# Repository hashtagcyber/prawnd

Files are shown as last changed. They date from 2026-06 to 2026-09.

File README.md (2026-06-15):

# Prawnd

An ESP32-based, Plaud-style voice recorder. Press a button to start/stop recording;
the device captures 16 kHz stereo audio to an SD card and POSTs each finished WAV
to a webserver you configure on-device.

- **Hardware** — Seeed XIAO ESP32C6, 2× INMP441 I²S mics (stereo), SPI microSD adapter, push-button. Wiring diagrams live in [`hardware/wiring.md`](hardware/wiring.md).
- **Firmware** — Arduino-ESP32 via PlatformIO. Source in [`firmware/`](firmware/).
- **Webservice** — Node.js + Fastify, SQLite-indexed, Dockerized. Source in [`server/`](server/).

> [!CAUTION]
> ## 🔓 HTTPS uploads use `setInsecure()` — TLS certificate validation is OFF
>
> When the configured Upload URL is `https://…`, the firmware uploads with
> `WiFiClientSecure::setInsecure()` (`firmware/src/uploader.cpp`), which **does
> the TLS handshake but does NOT validate the server's certificate**. The
> connection is encrypted, but there is **no protection against a
> man-in-the-middle**: anyone who can intercept the device's traffic can present
> a forged certificate, decrypt the upload, and **steal the API key** (which the
> device sends as `Authorization: Bearer …`).
>
> This is a **beta convenience only.** Before any non-hobby/production use, pin a
> CA bundle (e.g. ISRG Root X1) via `setCACert()` and remove `setInsecure()`, and
> treat each device's API key as compromised if its network is ever untrusted.
> Rotate keys in the web UI if in doubt.

## Quick start

```bash
# 1. Bring the server up locally
cd server
cp .env.example .env            # then edit PRAWND_API_KEY
docker compose up -d --build
curl -s http://localhost:8080/healthz   # {"ok":true}

# 2. Build the firmware
cd ../firmware
pio run                                  # first run downloads toolchains (slow)

# 3. Flash it (with the XIAO plugged in via USB-C)
pio run -t upload
pio device monitor                       # 115200 baud
```

On first boot the device has no WiFi configured, so it brings up an AP named
**`Prawnd-XXXX`** (password `prawnd1234`). Connect, browse to `http://192.168.4.1`,
fill in WiFi creds + upload URL + API key, hit save. The device reboots into STA
mode and is ready to record.

## Server

### Prereqs
- Docker / Docker Compose (Rancher Desktop, OrbStack, or Docker Desktop all fine)

### Build & run
```bash
cd server
cp .env.example .env       # set PRAWND_API_KEY
docker compose up -d --build
docker compose logs -f prawnd
```

The container exposes port `8080`, persists data under `./data/` on the host
(SQLite at `data/prawnd.sqlite`, WAVs under `data/audio/<device_id>/<yyyy>/<mm>/`).

### Browser UI

Visit `http://localhost:8080/` for a built-in single-page UI: enter your API key
once (cached in `localStorage`), filter by device id, and play back any recording
inline. Audio elements stream from `/recordings/:id/file?api_key=...` directly.
**Caveat**: the API key ends up in `<audio src>` attributes, so treat the URL as
secret on the LAN — don't share screenshots of the DOM.

### Endpoints

| Method | Path | Auth | Purpose |
|---|---|---|---|
| `GET`  | `/` | no | Built-in HTML UI. |
| `POST` | `/upload` | yes | Upload a WAV body. Headers: `Authorization: Bearer <key>` (or `X-API-Key: <key>`), `Content-Type: audio/wav`, `X-Device-Id: <id>`, `X-Client-Timestamp: <ms>` (optional). |
| `GET`  | `/recordings?limit=&cursor=&device_id=` | yes | Cursor-paginated list, newest first. |
| `GET`  | `/recordings/:id` | yes | JSON metadata. |
| `GET`  | `/recordings/:id/file` | yes | Raw `audio/wav` download. Auth accepts `?api_key=` query for `<audio>` playback. |
| `GET`  | `/healthz` | no | Liveness. |

API key auth accepts any of: `Authorization: Bearer <key>` header, `X-API-Key: <key>` header, or `?api_key=<key>` query param.

### Manual upload (smoke test without firmware)
```bash
curl -fsS -X POST \
  -H "Authorization: Bearer $PRAWND_API_KEY" \
  -H "Content-Type: audio/wav" \
  -H "X-Device-Id: bench" \
  --data-binary @some.wav \
  http://localhost:8080/upload
curl -fsS -H "Authorization: Bearer $PRAWND_API_KEY" http://localhost:8080/recordings | jq
```

### Stop / clean
```bash
docker compose down            # stop
rm -rf data && mkdir data      # wipe all recordings + db
```

## Firmware

### Prereqs
- [PlatformIO Core](https://platformio.org/install/cli) (`brew install platformio` on macOS)
- A USB-C cable that carries data
- A microSD card formatted **FAT32**

### Build
```bash
cd firmware
pio run
```
First run pulls the `espressif32` platform, the Arduino-ESP32 framework, the
toolchain, and the listed libs — expect several minutes on a fresh machine.
Subsequent builds take seconds. The flashable binary lands at
`.pio/build/xiao_esp32c6/firmware.bin`.

### Flash
Plug the XIAO in via USB-C. The C6 enters bootloader automatically on most
ports; if not, hold the **BOOT** button, tap **RESET**, then release BOOT.

The compiled artifact is `.pio/build/xiao_esp32c6/firmware.bin` (~1.1 MB).
```bash
pio run -t upload                # build + flash
pio run -t upload -t monitor     # flash + open serial monitor
```
Set the port explicitly if PlatformIO can't auto-detect:
```bash
pio run -t upload --upload-port /dev/cu.usbmodem<TAB>
```

### Serial monitor
```bash
pio device monitor               # 115200 baud (configured in platformio.ini)
```

### Optional: battery-monitoring addon

A second PlatformIO env, **`xiao_esp32c6_batt`**, compiles in an optional
MAX17048 LiPo fuel-gauge driver. The base `xiao_esp32c6` build is unchanged — the
addon is purely a compile-time flag (`-DENABLE_BATTERY`), so the standard
USB-powered firmware carries no battery code.

```bash
pio run -e xiao_esp32c6_batt              # build the battery variant
pio run -e xiao_esp32c6_batt -t upload    # build + flash it
```

Wire a MAX17048 breakout to the XIAO's I²C pins (`D4`=SDA, `D5`=SCL) and the BAT
pads — see [`hardware/wiring.md`](hardware/wiring.md#battery-fuel-gauge--max17048-optional-addon).
When a gauge is detected, `GET /status` gains `batt_pct` and `batt_mv` fields and
the config page shows the charge level; with no gauge fitted it reports
`battery: n/a` and behaves identically to the base firmware. The artifact lands
at `.pio/build/xiao_esp32c6_batt/firmware.bin`.

### First-time WiFi + upload setup
1. After flash, the device has no NVS config → it boots into AP mode.
2. From a phone or laptop, join the WiFi network **`Prawnd-XXXX`** (password `prawnd1234`, where `XXXX` is the last 4 hex of the MAC).
3. Open `http://192.168.4.1`.
4. Enter:
   - WiFi SSID + password (your home/office WiFi)
   - Upload URL — either:
     - **Local server:** `http://<your-mac-IP>:8080/upload` (plain HTTP), or
     - **Hosted beta:** `https://prawnd.dev.cobl.io/upload` (HTTPS — see the
       certificate-validation caution at the top of this README).
   - API key:
     - Local server: must match the server's `PRAWND_API_KEY`.
     - Hosted beta: log in at `https://prawnd.dev.cobl.io` with cobl.io and
       generate an **upload key** under *API keys*.
   - Device id (optional; auto-derived from MAC)
5. Hit **Save and reboot**. The device reconnects in STA mode.

To find the device's IP after reboot, watch the serial monitor or check your
router's DHCP list. `GET http://<device-ip>/status` returns its current state.

### Troubleshooting the first build

The `firmware/platformio.ini` deliberately uses the **pioarduino** platform fork
(`https://github.com/pioarduino/platform-espressif32/releases/...`) because the
official `platform-espressif32` still bundles Arduino-ESP32 v2.x, which has no
ESP32-C6 support. Two snags you may hit on a fresh machine:

- **`Could not find a version that satisfies the requirement cryptography` from pip** — your global pip is pointing at a local mirror that isn't serving. Override for the one command: `PIP_INDEX_URL=https://pypi.org/simple/ pio run`.
- **`FileNotFoundError: 'package-postinstall.py'` from the pioarduino esptool zip** — the v4.8.6 release omits the post-install script that PlatformIO tries to run. Stub it once: `touch ~/.platformio/packages/tool-esptoolpy/package-postinstall.py`, then re-run `pio run`.

### Recording flow
- **Short-press button** — start recording (LED on board lights, serial logs path)
- **Short-press again** — stop, patch WAV header, queue for upload, POST to server
- **Long-press ≥ 5 s** — factory reset (wipes NVS, reboots into AP mode)

Pending uploads (WiFi down, server unreachable) land in `/pending/` on the SD
card and retry once a minute while the device is idle and connected. Successfully
uploaded files move to `/uploaded/`.

## End-to-end verification

1. `cd server && docker compose up -d` — confirm `/healthz` returns 200.
2. `cd ../firmware && pio run -t upload && pio device monitor` — flash and watch boot logs.
3. Join the AP, configure with the upload URL pointing at your machine's LAN IP (NOT `localhost` — that's the device's own loopback).
4. Press the button, speak for a few seconds, press again.
5. Watch the serial log for `Upload .../ -> 200`.
6. `curl -fsS -H "Authorization: Bearer $PRAWND_API_KEY" http://localhost:8080/recordings | jq` — your recording shows up at the top.
7. Pull the file: `curl -fsS -H "Authorization: Bearer $PRAWND_API_KEY" http://localhost:8080/recordings/<id>/file -o out.wav` and play in VLC/Audacity — both L and R channels should be populated.

## Project layout

```
prawnd/
├── README.md
├── hardware.md                # high-level spec
├── hardware/
│   └── wiring.md              # per-device wiring diagrams + pin map
├── firmware/
│   ├── platformio.ini
│   ├── include/pins.h
│   └── src/                   # main, audio, wav, sd, wifi, portal, uploader, button, config,
│                              #   battery (optional MAX17048 addon, -DENABLE_BATTERY)
└── server/
    ├── Dockerfile
    ├── docker-compose.yml
    ├── package.json
    ├── .env.example
    └── src/                   # server.js, db.js, auth.js, wav.js,
                               #   routes/ (upload, recordings, health, ui)
```

## Hardware Links
I purchased the following parts on Amazon:
- https://a.co/d/0gR9T4nS
- https://a.co/d/04cU7Vte
- https://a.co/d/02JYXZO7
- https://a.co/d/06rkL2Dp

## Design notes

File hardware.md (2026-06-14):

# Prawnd
ESP32 Clone of Plaud

The device has a configuration page where you can enter a URL and API key. When a recording completes, it's automatically uploaded to a webserver
The same page is how you configure the wifi access.

A start/stop button is used to start/stop recording

## Hardware
- 1x Seeed Studio XIAO ESP32C6
- 2x INMP441
- 1x WWZMDiB 6 Pcs Micro SD TF Card Adapter Mini Reader Module 3.3V 6 Pin SPI Interface
- 1x button
- *(optional)* 1x MAX17048 LiPo fuel-gauge breakout + single-cell LiPo — battery-monitoring addon, see `hardware/wiring.md`

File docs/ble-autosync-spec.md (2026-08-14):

# Prawnd BLE Auto-Sync Rearchitecture — Implementation Spec

Status: implementation-ready. Version 1.0. Audience: two implementation agents
(Firmware; iOS + Server). Section **B (Shared BLE Contract)** is the binding
coordination boundary — both sides implement only against it and must not need
to talk to each other. Sections C/D/E are per-agent. F/G/H apply to both.

> Hardware note (verified against `firmware/platformio.ini`): the firmware
> targets a **Seeed XIAO ESP32-C6** (not an ESP32-S3 as the brief states). The
> spec is written for the C6; everything here is SoC-agnostic except memory
> budgets, which assume the C6's single RISC-V core + ~512 KB SRAM. This does
> not change the BLE contract.

---

## A. Overview & Goals

### Target architecture

Today the device drains its on-SD `/pending/*.wav` queue via **two** uplinks: a
firmware WiFi HTTPS uploader (`uploader.cpp`, states `ApPortal`/`Uploading`) and
an iOS app over a custom BLE GATT contract. The rearchitecture **removes WiFi
entirely from the firmware** and makes **the phone-over-BLE path the sole
uplink**. The firmware no longer knows the server URL or API key — those live
only in the iOS app. The device only: records audio, queues WAVs to SD, serves
them over BLE, and advertises *whether it has pending recordings* so iOS can
discover-and-wake the app in the background.

Three roles:

- **Device (ESP32-C6, NimBLE peripheral):** records to `/pending`, advertises a
  "pending present" bit, serves a reliable chunked file-transfer GATT service,
  moves files `/pending → /uploaded` on ACK, clears the pending bit when the
  queue empties.
- **iOS app (Core Bluetooth central, background-capable):** holds the server
  credentials, auto-connects to the bonded device when it sees the pending bit
  (even when backgrounded/relaunched via Core Bluetooth **state restoration**),
  drains the queue reliably, POSTs each WAV to the server, ACKs the device.
- **Server (Node/Fastify):** unchanged contract plus **content-hash
  idempotency** so a retried background upload never double-stores.

The key constraint driving the whole design: **iOS background BLE is slow and
its wake windows are short.** Background scanning is coalesced/duty-cycled by
the OS, cannot use `CBCentralManagerScanOptionAllowDuplicatesKey`, and *requires
explicit service UUIDs in the scan filter* (a service UUID present only in the
scan-response is invisible to background scans). A background wake from a BLE
discovery grants only a few seconds of runtime — not enough to pull a multi-MB
WAV and HTTP-POST it inline. We therefore design so that:

1. The device advertises the **128-bit service UUID in the primary advertising
   packet** (not scan-response) at all times, so iOS background scan can match.
2. The **HTTP upload is handed to a background `URLSession`** (out-of-process,
   OS-managed, survives app suspension/termination), so the wake window only has
   to cover BLE pull + enqueue, not the network transfer.
3. The BLE transfer itself is **reliable and resumable** (length-prefixed,
   CRC'd, windowed-ACK chunks) so a wake window that ends mid-file can resume on
   the next wake instead of restarting.

This is the best achievable on iOS. See **H** for the honest limits (notably:
true "app fully closed" wake works only via state restoration after at least one
launch, and large files may take several wake windows).

### End-to-end happy path (ASCII sequence)

```
 USER        DEVICE (ESP32-C6)                 iOS APP (bg)              SERVER
  |   press        |                                |                       |
  |--------------->| record -> /pending/<ts>.wav    |                       |
  |   press        | patch WAV header               |                       |
  |--------------->| stopRecording()                |                       |
  |                | set PENDING bit in adv mfg-data|                       |
  |                | advertise(svcUUID in primary,  |                       |
  |                |           pending=1)            |                       |
  |                |        ~~~ adv ~~~~~~~~~~~~~~~~> | OS bg scan match      |
  |                |                                 | (relaunch app if     |
  |                |                                 |  killed, via state    |
  |                |                                 |  restoration)         |
  |                |                                 | connect(known periph) |
  |                | onConnect (encrypted, bonded)  <-| (no timeout in bg)   |
  |                | link encrypts (resolve RPA)    <-> bond resolves        |
  |                |                                 | discover svc/chars    |
  |                |                                 | subscribe DATA/STAT   |
  |                |<-- CTRL: LIST ------------------|                       |
  |                |--- STAT: F <name> <size> <crc> >|                       |
  |                |--- STAT: FEND <count> -------- >|                       |
  |                |<-- CTRL: GET <name> <off=0> --- |                       |
  |                |--- STAT: GS <name> <size> <crc> >|                      |
  |                |--- DATA: [seq|len|payload] ---->| (window of N)         |
  |                |<-- CTRL: ACKW <next_seq> ------ | (windowed ACK)        |
  |                |--- DATA: ... -----------------> | ... until EOF         |
  |                |--- STAT: GE <name> <crc_ok> -- >| verify CRC            |
  |                |                                 | enqueue bg URLSession |
  |                |                                 |---- POST /upload ----->|
  |                |                                 |   (X-Content-Sha256)  |
  |                |                                 |<--- 200 {id} / 409 ---|
  |                |<-- CTRL: ACK <name> ----------- | (after 2xx OR 409 dup)|
  |                | mv /pending/<n> -> /uploaded/<n>|                       |
  |                |--- STAT: OK <name> ----------- >|                       |
  |                | if /pending empty: PENDING bit=0|                       |
  |                | refreshAdvertising(pending=0)   |                       |
  |                |        ~~~ adv (pending=0) ~~~~> | nothing to do, idle   |
```

Fallback "manual sync": identical from `connect()` onward; just triggered by the
user tapping **Sync** in the foreground instead of by a background wake.

---

## B. Shared BLE Contract (binding coordination boundary)

Both implementers depend **only** on this section. Everything is little-endian
unless stated. "ATT payload" = negotiated MTU − 3.

### B.1 GATT service & characteristics

Reuse the existing 128-bit base UUID family `E2C5xxxx-7C6E-4F1D-9B1A-9B6A4F2D8A01`.
Existing UUIDs are kept where they still fit; new ones are added for config and
flow control. **Uppercase is canonical; firmware string literals may be
lowercase — they are the same UUID.**

| Name | UUID | Properties | Encryption | Direction / purpose |
|---|---|---|---|---|
| SVC | `E2C50000-7C6E-4F1D-9B1A-9B6A4F2D8A01` | (service) | — | Prawnd Sync service |
| CTRL | `E2C50001-7C6E-4F1D-9B1A-9B6A4F2D8A01` | Write, WriteNR, **WriteEnc** | required | phone → device commands (incl. windowed ACK) |
| STAT | `E2C50002-7C6E-4F1D-9B1A-9B6A4F2D8A01` | **Notify**, ReadEnc | required\* | device → phone control/status (text lines) |
| DATA | `E2C50003-7C6E-4F1D-9B1A-9B6A4F2D8A01` | **Notify** | required\* | device → phone framed file chunks |
| CFG | `E2C50004-7C6E-4F1D-9B1A-9B6A4F2D8A01` | **ReadEnc, WriteEnc** | required | device config (device_id, fw version, caps) |

\* STAT/DATA notifications inherit link encryption because the link is forced
encrypted before any command is accepted (CTRL is WriteEnc). The CCCDs are
written by the central after the link is encrypted.

**MTU / chunk negotiation.** Device requests ATT MTU 517 at init; iOS negotiates
down (typically 185 foreground, often 23–185 background). Both sides compute the
DATA payload size as `mtu - 3 - DATA_HEADER (4)` (see B.4). The device exposes
the *current* negotiated MTU back to the app via the `GS` line's `<mtu>` field so
the app can sanity-check. Neither side hardcodes a chunk size.

### B.2 Advertising format (load-bearing for background wake)

Primary advertising packet (≤31 bytes), built every time pending-state or
pairing-state changes:

```
Flags (LE General Disc + BR/EDR unsupported)            3 bytes
Complete 128-bit Service UUID = SVC                    18 bytes   <-- MUST be in PRIMARY pkt
Manufacturer Specific Data                              7 bytes
  -> company id 0xFFFF (2) + payload (4):
       byte[0] = PROTO_VER   (0x02 for this spec)
       byte[1] = FLAGS bitfield:
                   bit0 (0x01) = PAIRING window open
                   bit1 (0x02) = PENDING recordings present
                   bit2 (0x04) = BUSY (a sync is in progress)
       byte[2] = pending count, clamped 0..255
       byte[3] = battery percent 0..100 (0xFF = unknown)
Total: 3 + 18 + 9 = 30 bytes  (fits 31)
```

Scan response: device **name** only (`Complete Local Name`).

Rules:
- The SVC UUID **must** be in the primary packet (not scan-response) so iOS
  background scanning — which only honours the primary packet and requires an
  explicit service-UUID filter — can match. (The current firmware already does
  this; keep it.)
- `PROTO_VER` byte lets the app detect old firmware and fall back to the legacy
  text protocol if desired (recommended: app refuses < 0x02 and shows "update
  firmware"). Old firmware used a 3-byte mfg payload `{0xFF,0xFF,pairingflag}`;
  the new layout is `{0xFFFF company}{ver,flags,count,batt}`. They are
  distinguishable by length (3 vs 4 payload bytes) and by company-id placement.
- Advertise **continuously** in every non-recording state. Pending bit toggles
  the FLAGS; the app distinguishes "wake me, there's work" (bit1=1) from "idle".
- Advertising interval: idle (pending=0) **1000–1285 ms** (power saving, still
  discoverable); pending=1 or pairing **152.5–211.25 ms** (fast discovery). The
  device bumps to the fast interval whenever bit1 or bit0 is set.

### B.3 Bonding / security model

- LE Secure Connections, **Just Works** (no passkey), bonding enabled.
  `setSecurityAuth(bond=true, mitm=false, sc=true)`, IO cap `NO_INPUT_NO_OUTPUT`.
- **New bonds are accepted only while the PAIRING window is open** (opened by a
  triple button press, 60 s). Outside the window, the device still advertises and
  still accepts connections from **already-bonded** centrals.
- **Bug #1 fix — RPA / reconnect:** Do **not** gate `onConnect` on
  `info.isBonded()` (unreliable: iOS uses rotating Resolvable Private Addresses
  and a not-yet-resolved RPA reads as unbonded at connect time). Instead:
  1. Configure the NimBLE **resolving list** and persist the **IRK** at bond
     time so the controller can resolve the peer's RPA on reconnect
     (`NimBLEDevice::setSecurityAuth` with bonding + ensure bonds persist in NVS;
     do **not** call anything that wipes bonds at boot).
  2. Enforce access via the **GATT layer, not the connect callback**: CTRL is
     `WriteEnc`, so an unbonded/unencrypted central simply cannot issue any
     command (the stack rejects the write with Insufficient Authentication and
     iOS auto-initiates pairing). In `onConnect`, **only** reject when
     `pairingMode == false` **and** the new pairing is not already encrypted —
     and even then, prefer to let encryption be demanded lazily by the WriteEnc.
     Concretely: remove the `!info.isBonded()` disconnect; rely on WriteEnc +
     the pairing-window gate on *new bond creation* (reject `onAuthentication`
     /new bonding outside the window, not reconnects of existing bonds).
- Encryption is required before LIST/GET/ACK/CFG are honoured (enforced by
  WriteEnc on CTRL and ReadEnc/WriteEnc on CFG/STAT).

### B.4 Wire protocol

Two planes: **STAT** carries newline-terminated, tab-delimited **text** control
lines (human-debuggable, evolves the existing protocol). **DATA** carries
**binary framed** file chunks. **CTRL** carries phone→device commands as text,
plus the binary windowed-ACK.

#### B.4.1 CTRL commands (phone → device)

Text, UTF-8, tab-delimited, **no trailing newline required**. One command per
write.

| Command | Meaning |
|---|---|
| `LIST` | enumerate `/pending`. Device replies on STAT with `F …` lines then `FEND`. |
| `GET\t<name>\t<offset>` | begin/resume sending `<name>` starting at byte `<offset>` (0 = from start). Device replies `GS …` then streams DATA frames from `<offset>`. |
| `ACK\t<name>` | mark `<name>` uploaded → move `/pending → /uploaded`. Device replies `OK`/`ERR`. |
| `ABORT\t<name>` | cancel an in-progress GET (e.g. wake window ending). Device stops streaming, replies `GA\t<name>`. |
| `WIN\t<n>` | (optional) set window size to `n` frames (1..32). Default 8. Persists for the connection. |

Plus the **binary** flow-control write on CTRL (distinguished from text by first
byte `0x01`, which is not a printable command char):

```
ACKW frame (phone -> device, on CTRL, WriteNR):
  byte[0]      = 0x01           (ACKW opcode marker)
  byte[1..4]   = next_seq (uint32 LE)   -- lowest seq number NOT yet received
                                           contiguously (cumulative ACK)
  byte[5]      = flags: bit0 = NAK (request retransmit from next_seq)
```

#### B.4.2 STAT lines (device → phone)

ASCII, `\t`-delimited, `\n`-terminated, one logical record per notification
(may be coalesced by the app's line buffer — the app MUST buffer and split on
`\n`, as it does today).

| Line | Meaning |
|---|---|
| `F\t<name>\t<size>\t<crc32>\n` | one pending file. `<crc32>` = CRC-32 (see B.4.4) of the whole file, hex, lowercase, 8 chars. Enables the app to dedup/verify without a full GET. |
| `FEND\t<count>\n` | end of LIST. |
| `GS\t<name>\t<size>\t<crc32>\t<mtu>\t<chunk>\n` | start of GET. `<chunk>` = DATA payload bytes/frame the device will use. |
| `GE\t<name>\t<crc_ok>\n` | end of file reached. `<crc_ok>` = `1` (device-side running CRC matched header CRC) or `0`. |
| `GA\t<name>\n` | GET aborted (response to `ABORT`). |
| `OK\t<name>\n` | ACK succeeded (file moved to `/uploaded`). |
| `ERR\t<code>\t<name>\n` | error; see B.4.5. `<name>` may be empty. |

#### B.4.3 DATA frames (device → phone, binary)

Each DATA notification is exactly one frame:

```
DATA frame layout:
  byte[0..3]  = seq      (uint32 LE)   -- 0-based frame index within this GET
  byte[4..5]  = len      (uint16 LE)   -- payload byte count (1..chunk)
  byte[6..N]  = payload  (len bytes of raw WAV file data)
Header = 6 bytes. Payload max = (negotiated MTU - 3) - 6.
```

- Frames are sent in strictly increasing `seq`. Byte offset of frame `seq` =
  `GET.offset + Σ(prior payload lens)`; because every frame except the last is
  exactly `<chunk>` bytes, `byte_offset = offset + seq*chunk`. The last frame may
  be shorter. (Keeping all-but-last full-size makes offset math O(1) for resume.)
- No CRC per frame (CRC is per-file, verified at `GE`). `len` + `seq` detect
  truncation/reorder/loss.

#### B.4.4 CRC

CRC-32 (IEEE 802.3, polynomial `0xEDB88320`, init `0xFFFFFFFF`, reflected,
final XOR `0xFFFFFFFF`) over the **entire file bytes** (WAV header included).
Emitted lowercase hex, zero-padded to 8 chars. Both sides compute identically.
The device computes file CRCs lazily and **caches** them (filename+size+mtime →
crc) so `LIST` is cheap on repeat (see C).

#### B.4.5 Error codes (`ERR\t<code>`)

| code | meaning |
|---|---|
| `nosd` | no SD card present |
| `notfound`  | file not in `/pending` |
| `badname` | name failed validation (`.`-prefixed, non-`.wav`, path sep) |
| `badoffset` | requested offset > file size |
| `rename` | SD rename failed during ACK |
| `busy` | another GET in progress (only one concurrent GET) |
| `internal`  | unexpected SD/read error |

### B.5 Reliable windowed transfer — exact state machines

One GET active per connection. Window size `W` (default 8, set via `WIN`).

**Device (sender) state machine for a GET:**

```
States: IDLE -> STREAMING -> DRAINING -> DONE/ABORTED

on CTRL "GET name offset":
   validate name/offset; if bad -> STAT ERR; stay IDLE
   open file, seek(offset)
   compute/lookup file size + crc32
   STAT: GS name size crc mtu chunk
   base = offset/chunk ; next_seq = base ; win_lo = base
   running_crc = (offset==0 ? fresh : recompute up to offset)   // see note
   state = STREAMING

STREAMING loop (cooperative, in bleSyncService, NOT a BLE callback):
   while next_seq < win_lo + W  and  not EOF  and  connected:
       read chunk bytes
       send DATA frame(seq=next_seq, payload)
       next_seq++
       if notify queue full -> break (retry next service tick)
   if EOF and next_seq == total_frames:
       state = DRAINING

on CTRL ACKW(next_ack, flags):
   if flags.NAK: next_seq = next_ack; reseek file to next_ack*chunk   // retransmit
   win_lo = next_ack                 // slide window; allows more sends
   (loop above resumes on next service tick)

DRAINING:
   when win_lo >= total_frames (all frames cumulatively ACKed):
       STAT: GE name crc_ok
       close file; state = IDLE

on CTRL ABORT name:  stop, close file, STAT GA name, state = IDLE
on disconnect:       close file, state = IDLE  (no data lost; /pending intact)
```

> Note on resume CRC: the device's `crc_ok` at `GE` is computed over the bytes it
> *actually sent this session starting at offset*. For a resumed GET
> (offset>0) the device cannot cheaply recompute the prefix CRC, so it sends the
> **full-file cached CRC** in `GS`/`GE` and sets `crc_ok=1` if the file is intact
> on disk (it always is — it's a closed file). **Authoritative verification is
> the app's**: the app concatenates the resumed bytes onto whatever it already
> had and checks the full-file CRC from `GS`. `crc_ok` is advisory.

**App (receiver) state machine for a GET:**

```
States: REQUESTED -> RECEIVING -> VERIFYING -> COMPLETE / FAILED

send CTRL "GET name offset"   (offset = bytes already persisted for name, else 0)
start per-GET watchdog timer (see B.6)

on STAT GS name size crc mtu chunk:
   expected_size=size; file_crc=crc; chunk=chunk
   expect_seq = offset/chunk
   buffer = (resume? existing partial : empty)

on DATA frame(seq,len,payload):
   reset watchdog
   if seq == expect_seq:
        append payload; expect_seq++
        every W/2 frames OR every 200ms: send ACKW(next=expect_seq)
   elif seq < expect_seq:  ignore (dup)
   else (seq > expect_seq): gap detected
        send ACKW(next=expect_seq, NAK)   // ask device to rewind
   if bytes_received >= expected_size: state = VERIFYING

on STAT GE name crc_ok:
   state = VERIFYING

VERIFYING:
   compute CRC-32 over assembled file bytes
   if == file_crc: COMPLETE -> hand to uploader, then send CTRL ACK name on 2xx
   else: persist partial (for resume), FAILED -> retry GET from last good offset

on STAT ERR / disconnect / watchdog:
   persist partial bytes to disk keyed by name (resume point), FAILED
```

### B.6 Timeouts (bug #2 fix) — both ends

The app sets a watchdog on **every** outstanding operation, not just connect:

| Operation | App-side timeout | On expiry |
|---|---|---|
| connect | 12 s (fg), **none** (bg restoration — let OS hold it) | fg: fail; bg: leave pending connect |
| service/char discovery + subscribe | 8 s | fail GET/sync |
| LIST (CTRL→FEND) | 8 s | fail, disconnect |
| GET (per-frame inactivity) | 5 s since last DATA/STAT | NAK once, then fail+persist partial |
| GET (overall) | 60 s | abort GET, persist partial, move on |
| ACK (CTRL→OK) | 8 s | treat as failed; do **not** re-upload (idempotency covers a possibly-applied ACK) |

The device has its own guards: if `STREAMING`/`DRAINING` and no ACKW progress
for 10 s, it stops streaming (window stalled) and waits; on disconnect it resets
to IDLE. The device never blocks the main loop > a few ms per service tick.

### B.7 Config flow over BLE (CFG characteristic)

CFG is a single Read/Write-encrypted characteristic carrying a small UTF-8 JSON
object (≤ 256 bytes; fits one or two ATT reads — app uses `readValue`, which
CoreBluetooth reassembles).

Read (device → app), JSON:
```json
{ "device_id":"prawnd-AB12", "fw":"2.0.0", "proto":2, "free_mb":1234, "pending":3 }
```

Write (app → device), JSON; only present keys are applied & persisted to NVS:
```json
{ "device_id":"my-recorder-1" }
```
- `device_id`: validated `^[A-Za-z0-9_-]{1,32}$`. On change, device persists to
  NVS (`config.cpp`), updates the advertised name, and the new id takes effect
  immediately (no reboot needed for the name; BLE re-advertises).
- Unknown keys ignored. Server URL / API key are **never** sent to the device.

This replaces the deleted captive portal as the *only* configuration surface.

---

## C. Firmware Spec (prawnd repo)

Target file: `firmware/`. Board: XIAO ESP32-C6 (`platformio.ini`).

### C.1 Files to DELETE

```
firmware/src/wifi_mgr.cpp
firmware/src/wifi_mgr.h
firmware/src/portal.cpp
firmware/src/portal.h
firmware/src/uploader.cpp
firmware/src/uploader.h
```

Symbols removed (no other consumers — verified, all only used by `main.cpp`):
`wifiTryStation`, `wifiStartAp`, `wifiInStaMode`, `wifiCurrentIp`,
`portalBegin`, `portalEnd`, `portalSaveRequested`, `uploadFile`.

### C.2 `platformio.ini` changes

- Remove `esp32async/ESPAsyncWebServer` and `esp32async/AsyncTCP` from
  `lib_deps` (only the portal used them). Keep `ArduinoJson` (now used by CFG)
  and `NimBLE-Arduino`.
- Remove `<WiFi.h>` usage. Note: on ESP32, NimBLE and WiFi share nothing
  required here; dropping WiFi reduces RAM/flash. `huge_app.csv` can stay or be
  reduced — keep `huge_app.csv` to avoid a repartition/erase churn (document it,
  but no need to change).
- `config.cpp` includes `<WiFi.h>` **only** for `WiFi.macAddress()` which it
  already avoids (it uses `ESP.getEfuseMac()`); drop the `#include <WiFi.h>`.

### C.3 `config.*` changes

New `Config` (drop WiFi fields):
```cpp
struct Config {
  String device_id;                 // NVS key "dev"
  bool valid() const { return device_id.length() > 0; }
};
```
- `loadConfig`: read only `"dev"`; default via `defaultDeviceId()` (keep eFuse
  MAC scheme `prawnd-XXXX`).
- `saveConfig`: persist only `"dev"`.
- Add `bool saveDeviceId(const String&)` convenience used by the CFG write path.
- `clearConfig()` unchanged (still wipes the `prawnd` NVS namespace on long
  press) — but note NimBLE bonds live in a **separate** NVS namespace managed by
  the BLE stack; long-press factory reset SHOULD also clear bonds
  (`NimBLEDevice::deleteAllBonds()`), document this.
- Drop keys `ssid`,`psk`,`url`,`key` (old NVS values become dead — harmless;
  `clearConfig` removes them; no migration needed).

### C.4 New main-loop state machine (`main.cpp`)

```cpp
enum class State { Boot, Idle, Recording };   // ApPortal/StaIdle/Uploading removed
```

Removed: `#include "wifi_mgr.h" / "portal.h" / "uploader.h"`,
`tryUploadOnce()`, `pendingUploadPath`, `lastDrainAt`, `firstDrain`,
`portalSaveRequested()` handling, all WiFi/AP boot logic.

`setup()`:
```
Serial, button, SPI, SD.begin(1MHz), ensureDirs()
#ifdef ENABLE_BATTERY: batteryBegin()/read()
loadConfig(cfg)                  // device_id only
bleSyncBegin(cfg.device_id)      // sets up GATT incl. CFG, resolving list, adv
updatePendingAdvertising()       // set PENDING bit per /pending contents at boot
state = State::Idle
```

`loop()`:
```
if buttonLongPressed():   clearConfig(); NimBLEDevice::deleteAllBonds(); restart
if buttonTriplePressed() && state != Recording:  bleSyncEnterPairing()

switch(state):
  Boot:      delay(20)
  Idle:
     bleSyncService();                 // drains one BLE step (LIST/GET window/ACK/CFG)
     if buttonShortPressed(): startRecording()
     else delay(5)                     // tighter loop so streaming stays fed
  Recording:
     // audio+SD in FreeRTOS tasks; BLE intentionally NOT serviced here
     if buttonShortPressed(): stopRecording()
     else delay(20)
```

`startRecording()`: unchanged pipeline, plus: before starting, the device should
**stop advertising the BUSY/streaming** and may keep advertising the service
(recording does not need BLE). Keep it simple: during Recording, do not service
BLE commands (matches today's behaviour); a connected phone's in-flight GET will
time out and resume later. Set FLAGS BUSY bit cleared.

`stopRecording()`: unchanged through `SD.rename` to `/pending/<ts>.wav`, then:
```
state = State::Idle
updatePendingAdvertising()    // sets PENDING bit=1, count, fast adv interval
```

### C.5 `ble_sync.*` rewrite

Add CFG characteristic; add binary DATA framing + windowed ACK; fix security.

New public API (`ble_sync.h`):
```cpp
void bleSyncBegin(const String &deviceId);
void bleSyncService();              // cooperative: advances LIST/GET/ACK/CFG + streaming window
bool bleSyncBusy();                 // connected AND a GET/transfer is active
void bleSyncEnterPairing();
bool bleSyncPairing();
void bleSyncSetDeviceId(const String&);   // applied from CFG write
// advertising helper used by main.cpp:
void bleSyncUpdatePending(uint32_t pendingCount, uint8_t batteryPct);
```

Implementation notes:

- **Advertising** (`refreshAdvertising`) builds the B.2 layout: SVC UUID in the
  primary packet, mfg-data `{0xFFFF, ver=2, flags, count, batt}`. Helper
  `bleSyncUpdatePending(count,batt)` recomputes flags (PENDING bit from
  `count>0`), sets the adv interval fast/slow accordingly, and restarts adv.
  Called from the main loop only (never from a BLE callback — keep today's rule).
- **Pending count** is computed by scanning `/pending` for valid `.wav` files
  (reuse `isRecordingName`). Cache the count; recompute after ACK and after
  `stopRecording`.
- **Security setup:** `setSecurityAuth(true,false,true)`,
  `setSecurityIOCap(NO_INPUT_NO_OUTPUT)`. **Remove the
  `!info.isBonded()` disconnect in `onConnect`** (bug #1). Gate *new bond
  creation* to the pairing window: in `onAuthenticationComplete`, if a **new**
  bond formed while `pairingMode==false`, delete that bond and disconnect; if it
  formed during the window, keep it and close the window. Ensure
  `NimBLEDevice::init` does not erase bonds; verify bonds persist across reboot
  (NimBLE stores them in NVS by default). Configure the resolving list so RPAs
  resolve — with NimBLE this is automatic once a bond with an IRK exists and
  `setSecurityAuth` enables it; do **not** add any code that clears
  `ble_store`. CTRL stays `WRITE_ENC` so unencrypted centrals cannot command.
- **Command handling** stays single-threaded: BLE callbacks only enqueue; all SD
  access happens in `bleSyncService()` from the main loop (preserve the mutex +
  `pendingCmd` pattern). Extend to parse the new commands (`GET name offset`,
  `ABORT`, `WIN`) and the binary `ACKW` on CTRL (detect first byte `0x01`).
- **LIST** emits `F name size crc` — compute CRC via the cache (C.6).
- **GET sender:** implement the B.5 device state machine. Replace the old blind
  `delay(6)` notify pacing with **window-gated** sending: send up to `win_lo+W`
  unacked frames, then wait for ACKW to slide the window. Use
  `dataChar->notify()` return / NimBLE's notify queue back-pressure: if a notify
  fails (buffers full), break and retry on the next service tick. Frame header
  is the 6-byte `{seq,len}` per B.4.3. **Remove `delay(6)` entirely.**
- **ACK** handler unchanged logic (rename `/pending → /uploaded`), then call
  `bleSyncUpdatePending(newCount,batt)` so the advertised PENDING bit clears when
  the queue empties.
- **CFG:** `ReadEnc` callback returns the JSON in B.7 (build with ArduinoJson);
  `WriteEnc` callback parses JSON, validates+persists `device_id`, calls
  `bleSyncSetDeviceId`. Keep all CFG work to enqueue-then-service if it touches
  SD/NVS heavily (NVS write is fine in callback but prefer servicing).

### C.6 CRC cache (SD/memory constraint)

Computing CRC-32 over a multi-MB WAV on every LIST is too slow on a 1 MHz SPI
SD. Maintain an in-RAM cache: `struct { String name; uint32_t size; uint32_t crc; }`
for up to ~16 entries (the pending queue is small). On `stopRecording`, compute
the new file's CRC once (streamed, 4 KB reads, ~tens of ms/MB acceptable at stop
time) and insert. On LIST, use cache; on miss (e.g. files copied onto the card),
compute lazily and cache. Persisting the cache is optional (recompute on boot is
acceptable since boots are rare). Memory: 16 × ~40 B ≈ negligible.

### C.7 Memory / SD / concurrency / power

- **Concurrency:** one GET at a time (`ERR busy` otherwise). All SD I/O on the
  main loop via `bleSyncService`; recording uses the existing two FreeRTOS tasks
  and BLE is **not** serviced during Recording — no SD contention.
- **Buffers:** DATA frame staging buffer = one chunk (≤ MTU−3−6 ≤ ~508 B);
  reuse a single static buffer. SD read buffer 4 KB for CRC. StreamBuffer (64 KB)
  only exists during Recording.
- **Notify back-pressure:** rely on NimBLE's `notify()` returning failure when
  the controller TX queue is full; never `delay()` to pace. The window scheme
  (W=8) bounds in-flight frames so the queue can't be flooded.
- **Power:** idle advertising at 1 s interval is the dominant idle draw; the fast
  interval only runs while pending>0 (i.e., until the phone drains). After the
  queue empties the device returns to slow advertising. Recording disables BLE
  servicing. (No sleep modes specified here; out of scope, see H.)

---

## D. iOS App Spec (plagueboxmobile repo)

Target: `native/ios/PrawndSync/PrawndSync/`. Deployment target iOS 17,
bundle id `io.cobl.dev.prawndsync`.

### D.1 Capabilities, Info.plist, entitlements

`Info.plist` additions:
```xml
<key>UIBackgroundModes</key>
<array>
  <string>bluetooth-central</string>
</array>
<key>NSBluetoothAlwaysUsageDescription</key>
<string>Prawnd Sync connects to your recorder over Bluetooth — including in the
background — to pull and upload your recordings automatically.</string>
```
- Keep existing `NSAppTransportSecurity / NSAllowsLocalNetworking` (LAN servers).
- No special entitlement file is required for `bluetooth-central` background mode
  (it is an Info.plist background mode, not an entitlement). Background
  `URLSession` also needs no entitlement.
- Enable the **Background Modes** capability in the target (adds the above key
  via Xcode); the project currently has no `.entitlements` file — none needs to
  be added for this feature.

### D.2 Core Bluetooth state restoration

Create the `CBCentralManager` with a **restore identifier** and implement
`willRestoreState`. This is what lets iOS **relaunch the app into the background**
when the bonded device is discovered after the app was terminated.

```swift
central = CBCentralManager(
    delegate: self,
    queue: .main,
    options: [CBCentralManagerOptionRestoreIdentifierKey: "io.cobl.dev.prawndsync.central"])
```

Implement:
```swift
func centralManager(_ c: CBCentralManager, willRestoreState dict: [String: Any]) {
   // Re-adopt restored peripherals; re-wire delegate; resume in-flight sync.
   if let ps = dict[CBCentralManagerRestoredStatePeripheralsKey] as? [CBPeripheral] {
       for p in ps where p.identifier.uuidString == SettingsManager.shared.pairedDeviceID {
           peripheral = p; p.delegate = self
           // if state == .connecting/.connected continue handshake
       }
   }
}
```

On `centralManagerDidUpdateState(.poweredOn)`:
- If a device is paired, **register a background discovery**:
  `central.scanForPeripherals(withServices: [svcUUID], options: nil)` — note
  **no `AllowDuplicates`** (ignored in background) and the service-UUID filter is
  **mandatory** for background scans.
- Also issue a standing `central.connect(knownPeripheral, options:
  [CBConnectPeripheralOptionNotifyOnConnection/Disconnection: true])` with **no
  timeout** for the paired peripheral (retrieved via
  `retrievePeripherals(withIdentifiers:)`). A pending connect persists across
  suspension; iOS completes it (and wakes the app) when the device is in range —
  this is the most reliable background wake, more so than scanning.

Recommended primary mechanism: **`connect` with no timeout to the known
peripheral** (works even when the device is just advertising and the app is
suspended), **backed by** the service-UUID background scan for the relaunch /
discovery case. Use both.

### D.3 Background execution strategy (the hard part — design around limits)

Hard limits (state them plainly):
- A BLE-triggered background wake gives only a **few seconds** of foreground-
  equivalent runtime. Not enough for a multi-MB BLE pull *and* an HTTP upload.
- `BGProcessingTask` can run longer but is **opportunistic** (the OS schedules it
  when it wants, typically on charge/at night) — unsuitable as the *only* path
  for "upload right after I recorded."

Chosen approach (concrete):
1. **BLE pull in the wake window.** On wake (connect/discovery), run the BLE
   drain. Pull as many files as the window allows. The **reliable resumable
   transfer (B.5)** means a file interrupted by the window ending is **persisted
   partially and resumed** on the next wake — no restart cost.
2. **HTTP upload via a background `URLSession`.** Do **not** upload inline with
   `URLSession.shared.data(for:)`. Instead use a single shared
   `URLSession(configuration: .background(withIdentifier:
   "io.cobl.dev.prawndsync.upload"))` with `isDiscretionary = false`,
   `sessionSendsLaunchEvents = true`. Write each pulled WAV to a temp file and
   create an **upload task from file** (`uploadTask(with:fromFile:)`). The OS
   performs the transfer **out of process**, surviving app suspension/termination,
   and relaunches the app via
   `application(_:handleEventsForBackgroundURLSession:completionHandler:)` /
   the SwiftUI `.backgroundTask(.urlSession(...))` modifier when done.
3. **ACK after upload confirmation, not after pull.** The device file stays in
   `/pending` until the server returns 2xx (or 409 duplicate). On the
   `URLSessionTaskDelegate didCompleteWithError` callback (which may fire in a
   *later* relaunch), the app reconnects BLE if needed and sends `ACK <name>`.
   To survive app death between upload-complete and ACK, persist a small
   **"awaiting ACK" set** (file name + device id) in UserDefaults; on launch /
   wake, drain it.
4. **`BGProcessingTask` as a safety net.** Register
   `io.cobl.dev.prawndsync.refresh` to periodically reconnect and drain anything
   stuck (device out of range during the original wake, etc.). Best-effort only.

Tradeoffs / honest limits → **H**.

### D.4 Redesigned `BLESyncManager`

Keep the `@MainActor`, continuation-based structure; change:

- **Auto-trigger on wake.** New entry point `func autoSyncIfPending(_ p:
  CBPeripheral, advFlags: UInt8?)`. Called from `didDiscover` (background scan
  match) and from `didConnect` (standing connect completed). If `advFlags`
  shows PENDING (bit1) or unknown, connect (if needed) and run the drain. The
  manual `sync()` remains and calls the same `runSync()`.
- **Per-command timeouts (bug #2 fix).** Wrap **every** continuation
  (`listCont`, `getCont`, `ackCont`, discovery/subscribe) in a watchdog per B.6,
  not just connect. Implement a helper:
  ```swift
  func withTimeout<T>(_ secs: Double, _ op: () async throws -> T) async throws -> T
  ```
  In **background**, the connect itself uses **no** app-side timeout (let iOS
  own it); per-command timeouts still apply once connected.
- **`subscribedCount` fix (bug #2).** Only increment on
  `didUpdateNotificationStateFor` when `error == nil`; require **both** STAT and
  DATA subscribed (count==2) **and** `ctrlChar != nil` before `resumeConnect()`.
  On subscription error, fail the connect continuation.
- **`deviceName` fix (bug #2).** On the `retrievePeripherals` fast path (no
  advertisement seen), set `deviceName = SettingsManager.shared.pairedDeviceName`
  immediately so uploads are filed under the real device id, never the literal
  `"prawnd"`. Better: stop using `deviceName` for `X-Device-Id` at all — read the
  authoritative id from the **CFG characteristic** once after connect and cache
  it (`SettingsManager.pairedDeviceID`-adjacent: store `pairedDeviceCfgId`). Use
  that for `X-Device-Id`. Falls back to `pairedDeviceName` then `"prawnd"`.
- **Reliable receiver (bug #3 fix).** Replace `handleData`/`finishGet` with the
  B.5 app receiver: parse the 6-byte DATA frame header, track `expect_seq`,
  send `ACKW` every `W/2` frames or 200 ms, NAK on gap, persist partial to disk
  for resume, verify full-file CRC at `GE`, retry/resume on mismatch or
  timeout. Drop the old "count bytes until >= size" heuristic.
- **Resume support.** Persist partial downloads to
  `FileManager … /Caches/partial/<deviceId>/<name>.part` plus a sidecar with
  bytes-received. On GET, send `offset = existing partial size`. On COMPLETE,
  move `.part` → temp and hand to the background uploader.
- **CFG read.** After connect+subscribe, `readValue(for: cfgChar)`; parse JSON;
  cache `device_id`, `fw`, `proto`. If `proto < 2`, surface "update firmware"
  and stop (do not attempt the new framing against old firmware).
- **One-GET discipline.** Serialize GETs (the device only does one).

### D.5 Uploader changes (`PrawndUploader.swift`)

- Add a background-`URLSession`-based path: `enqueueUpload(name:fileURL:deviceId:
  sha256:)` that builds the same request (Bearer, `audio/wav`, `X-Device-Id`,
  `X-Client-Timestamp`) **plus** a new header **`X-Content-Sha256: <hex>`** (see
  E) and creates `uploadTask(with:fromFile:)` on the shared background session.
- Keep the existing synchronous `upload(...)` for the foreground manual path /
  unit tests, but route auto-sync through the background session.
- Implement `URLSessionDelegate`/`URLSessionTaskDelegate` (likely on a small
  dedicated object owned by the app, since the session must outlive views):
  `didCompleteWithError` → on success/409 mark "awaiting ACK"; on transient
  failure the background session retries automatically.
- Compute SHA-256 of the WAV (CryptoKit `SHA256`) for the idempotency header and
  to dedup locally.

### D.6 UI changes

- `SyncView`: add an **auto-sync status** line ("Auto-sync on — last synced N min
  ago / N pending"). Keep the **Sync** button as a manual fallback (calls
  `ble.sync()`). Remove copy that implies sync only happens when the user taps.
- `PairView`: filter on the new mfg-data — **PAIRING bit = byte[1] bit0** (the
  layout moved; old code read byte index 2 of a 3-byte payload; new payload is
  `{ver,flags,count,batt}` after the 2-byte company id, so within
  `CBAdvertisementDataManufacturerDataKey` the bytes are `[0xFF,0xFF,ver,flags,
  count,batt]` → **flags is index 3, PAIRING = `mfg[3] & 0x01`**). Update the
  `pairingFlag` extraction accordingly.
- `SettingsView`: add an optional **device_id** editor that writes the CFG
  characteristic (connect, write JSON, disconnect). Server URL / API key
  unchanged. Show firmware version (from CFG).
- `SettingsManager`/`APIKeyManager`: **unchanged** (Keychain service
  `io.cobl.dev.prawndsync`/account `api_key`, accessible AfterFirstUnlock — which
  is correct for background use; do not change to WhenUnlocked or background
  uploads break while the phone is locked). Add a `pairedDeviceCfgId` and a
  small persisted "awaiting ACK" list (UserDefaults).

### D.7 Edge cases

| Case | Behaviour |
|---|---|
| App killed by user | iOS won't relaunch for BLE until the app is launched once more; after that, state restoration + standing connect resume background wake. Document for users (manual launch once after force-quit). |
| Bluetooth off | `centralManagerDidUpdateState` → `.poweredOff`; show status; auto-resume when back on. |
| Out of range during wake | Standing no-timeout `connect` stays pending; completes later. `BGProcessingTask` net catches stragglers. |
| Partial transfer | Persisted `.part` + offset; resumed via `GET name <offset>`; CRC verified at end. |
| Duplicate upload | Background session may retry; server dedups on `X-Content-Sha256` (E). App still ACKs the device on 200 **or** 409. |
| Upload completes but app dies before ACK | "Awaiting ACK" set persisted; drained on next launch/wake → reconnect, send `ACK`. Device idempotent (file already moved → `ERR notfound` is treated as success). |
| Device records again mid-drain | New file appears in next LIST; advertised count increments; handled next pass. |
| Two GETs requested | App serializes; device returns `ERR busy` if violated. |

---

## E. Server Spec (prawnd/server)

Current `/upload` (verified `server/src/routes/upload.js`): POST, auth via
`Authorization: Bearer` / `X-Api-Key` / `?api_key` matching `PRAWND_API_KEY`;
body is raw `audio/wav`/`application/octet-stream` (200 MB limit); headers
`X-Device-Id` (sanitized, default `unknown`) and `X-Client-Timestamp` (→
`client_ts`); generates a fresh **ULID per request**, stores
`audio/<device>/<yyyy>/<mm>/<id>.wav`, computes and stores **`sha256`** in the
`recordings` row, runs inline denoise → `<id>.cleaned.wav`. **It is NOT
idempotent today** — re-posting the same WAV creates a second row/file. SHA-256
is computed but never used for dedup.

Minimal change — **content-hash idempotency**:

1. Accept an optional request header **`X-Content-Sha256: <hex64>`**. If absent,
   server computes it from the body as today (still authoritative — server
   re-hashes regardless; the header is an optimization/assertion).
2. After hashing, **before inserting**, look up an existing recording with the
   same `(device_id, sha256)`:
   - Add a unique index:
     `CREATE UNIQUE INDEX IF NOT EXISTS uniq_recordings_device_sha
        ON recordings(device_id, sha256);`
     (in `db.js` migration; existing dup rows, if any, must be de-duplicated
     once before adding — document a one-time cleanup or use
     `CREATE UNIQUE INDEX … ` guarded by a pre-check).
   - If a row exists: **do not** store a second file; return **HTTP 409** (or
     **200** with the existing record + `"duplicate": true`). **Recommendation:
     return 200 with `{ "id": <existingId>, "duplicate": true, ... }`** so the
     client treats it as success and ACKs the device. (Simpler client logic than
     409.) If you prefer 409, the client (D) already treats 409 as ACK-worthy.
3. If `X-Content-Sha256` is present and mismatches the server-computed hash,
   return **400 `sha_mismatch`** (detects corruption in transit; the BLE CRC
   already guards the device→phone hop, this guards phone→server).
4. Keep everything else (auth, denoise, WAV parse, response shape) unchanged.
   Add `duplicate` (bool) to the success JSON.

No change to auth, body parsing, or storage layout. This makes background
retries and the "uploaded-but-ACK-lost" edge safe.

---

## F. Migration / Removal Checklist

**Firmware — delete files:**
- `firmware/src/wifi_mgr.cpp`, `wifi_mgr.h`
- `firmware/src/portal.cpp`, `portal.h`
- `firmware/src/uploader.cpp`, `uploader.h`

**Firmware — remove symbols / code:**
- `main.cpp`: includes of the three deleted headers; `State::ApPortal`,
  `State::StaIdle`, `State::Uploading`; `tryUploadOnce()`; `pendingUploadPath`,
  `lastDrainAt`, `firstDrain`; `portalSaveRequested()` block; WiFi/AP boot block.
- `config.h/.cpp`: drop `ssid`,`psk`,`upload_url`,`api_key` fields and NVS keys
  `"ssid"`,`"psk"`,`"url"`,`"key"`; `valid()` now checks `device_id` only.
- `platformio.ini`: drop `ESPAsyncWebServer`, `AsyncTCP` from `lib_deps`; drop
  `#include <WiFi.h>` from `config.cpp`.

**Firmware — add:**
- CFG characteristic + JSON read/write (`ble_sync.cpp`), `bleSyncSetDeviceId`,
  `bleSyncUpdatePending`, CRC-32 helper + cache, binary DATA framing + windowed
  ACK, `ABORT`/`WIN`/`GET offset` handling, advertising layout v2, security fix
  (remove `!isBonded()` gate; bond-window enforcement in auth-complete;
  `deleteAllBonds()` on factory reset).

**iOS — remove assumptions:**
- Manual-only sync UI copy; the old 3-byte mfg-data pairing-flag offset
  (index 2 → now index 3); the byte-count "finishGet" heuristic.

**iOS — add:**
- `UIBackgroundModes:[bluetooth-central]`, background-mode capability; CB restore
  identifier + `willRestoreState`; standing no-timeout connect + svc-filtered
  background scan; background `URLSession` upload path + delegate + launch-event
  handler; per-command timeouts; reliable framed receiver + resume; CFG read +
  device-id editor; "awaiting ACK" persistence; SHA-256 + `X-Content-Sha256`.

**iOS — config keys (UserDefaults):** keep `server_url`, `paired_device_id`,
`paired_device_name`; add `paired_device_cfg_id`, `awaiting_ack` (array of
`{name,deviceId}`). Keychain unchanged.

**Server — add:**
- Unique index `(device_id, sha256)`; dedup lookup before insert → 200
  `duplicate:true`; optional `X-Content-Sha256` validation (`400 sha_mismatch`);
  `duplicate` field in success response.

---

## G. Test & Acceptance Plan

### G.1 Firmware (independent, against contract)

- **Adv format:** use `nRF Connect` (or a host BLE script) to confirm: SVC UUID
  in primary packet; mfg-data `[FF FF 02 <flags> <count> <batt>]`; PENDING bit
  toggles after record/ACK; adv interval fast when pending.
- **Security:** unbonded central writing CTRL → Insufficient Authentication; pair
  during window → bond persists across reboot; **reconnect after reboot using a
  fresh RPA succeeds and can LIST** (bug #1 regression test). New connection
  while pairing window closed: existing bond OK, brand-new bond rejected.
- **Transfer:** scripted central performs `GET name 0`, validates frame
  `{seq,len}` monotonic, sends `ACKW`, induces a gap (drop a notify) → device
  retransmits on `NAK`; full-file CRC matches `GS` value; `GET name <offset>`
  resumes correctly.
- **Config:** read CFG → JSON with device_id/fw/proto; write `{"device_id":"x"}`
  → persists, advertised name changes, survives reboot.
- **Acceptance:** all of the above pass with no `delay()`-based pacing in the
  send path; main loop never blocked > ~20 ms; no SD access during Recording.

### G.2 iOS (independent, against contract)

- **Mock device:** a small CoreBluetooth-peripheral or host script implementing
  Section B. Verify: per-command timeouts fire (kill the mock mid-LIST/mid-GET →
  continuation fails within budget, no hang — bug #2); `subscribedCount` only
  counts successful subscribes; `deviceName`/cfg-id never defaults to `"prawnd"`
  when a name/CFG is available.
- **Reliable receiver:** mock drops/reorders DATA frames → app NAKs and recovers;
  CRC mismatch → app retries/resumes; partial persisted and resumed across an
  app relaunch.
- **Background:** with restore identifier set, force-relaunch the app process
  (Xcode "Wait for executable to launch" + toggle BT / use a real device) and
  confirm `willRestoreState` re-adopts the peripheral; standing connect completes
  and triggers `autoSyncIfPending`; background `URLSession` upload completes after
  suspension and the launch-event handler runs; ACK sent in a later wake.
- **Acceptance:** a recorded file uploads with the app backgrounded and never
  foregrounded after the initial install/launch; duplicate POST returns
  `duplicate:true` and still ACKs.

### G.3 Server (independent)

- POST same WAV twice (same device) → second returns 200 `duplicate:true`, no
  second file/row. Different device, same bytes → two rows (per-device dedup).
- `X-Content-Sha256` mismatch → 400 `sha_mismatch`. Absent header → still works.
- Auth unchanged (401 paths intact).

### G.4 Integration

1. Record on device → confirm PENDING adv bit set.
2. Phone backgrounded → wakes, drains, uploads, ACKs → device PENDING bit clears,
   file in `/uploaded`, server has exactly one recording.
3. Pull the phone out of range mid-GET → device keeps file; phone resumes on
   reconnect; final CRC ok; single server record.
4. Kill app, record again, relaunch once → subsequent records auto-sync in
   background.

**Top-level acceptance criteria:**
- Zero WiFi code/symbols remain in firmware; firmware contains no server URL/API
  key.
- A completed recording reaches the server **with no user interaction** while the
  app is backgrounded (after one prior launch).
- Bug #1: bonded iOS phones reconnect after RPA rotation and reboot — verified.
- Bug #2: no operation can hang indefinitely; all have timeouts; deviceName/cfg
  filing correct; `subscribedCount` correct.
- Bug #3: file transfer survives dropped notifications and verifies via CRC;
  short/stalled transfers self-heal via NAK/resume.
- No duplicate server-side recordings under retries.

---

## H. Open Questions / Risks (with recommendations)

1. **True "app fully closed" background wake.** iOS only relaunches a terminated
   app for Core Bluetooth events if state restoration is configured **and** the
   app has been launched at least once since install/force-quit. *Recommendation:*
   accept this; document the "launch once" requirement; rely on standing connect
   + state restoration. There is no way around the post-force-quit gap.

2. **Large WAVs vs short wake windows.** A multi-MB file may not finish in one
   background BLE window. *Recommendation (chosen):* resumable transfer (B.5) so
   progress is never lost; background `URLSession` for the HTTP leg so the network
   transfer doesn't compete for the wake window. Additionally, **cap recording
   length** or **roll over to a new file every ~60 s** of audio so individual
   files stay ≤ ~2 MB and usually drain in one window. *Default:* keep current
   record-until-pressed behaviour but flag rollover as a fast-follow.

3. **Windowed-ACK vs indications.** Indications give per-PDU acknowledgement but
   are slow (one outstanding at a time) and CoreBluetooth gives the app no extra
   reliability over notifications in practice. *Recommendation (chosen):* keep
   NOTIFY for throughput + app-level windowed ACK/NAK + per-file CRC. Best
   throughput/reliability balance; fully specified in B.5.

4. **CRC-32 vs SHA-256 on device.** SHA-256 over multi-MB on a 1 MHz SD + RISC-V
   core is slow. *Recommendation:* CRC-32 for the BLE hop (cheap, cached), and the
   phone computes SHA-256 only once on the assembled file for the server
   idempotency header. Two different integrity layers, each cheap where it runs.

5. **Server dedup response code.** 200+`duplicate:true` vs 409. *Recommendation:*
   200+`duplicate:true` (simplest client logic); client treats both as ACK-worthy
   regardless, so either is safe.

6. **Pairing-window enforcement location.** Enforcing "new bonds only during the
   window" in `onAuthenticationComplete` (delete-and-disconnect a new bond formed
   outside the window) is slightly racy but correct. *Recommendation:* implement
   it there and add a regression test (G.1). Reconnections of existing bonds are
   never affected.

7. **Power/sleep.** This spec does not add deep-sleep. Idle advertising at 1 s is
   the main idle cost. *Recommendation:* leave sleep out of scope; revisit after
   measuring real idle draw with WiFi removed (WiFi removal alone should cut idle
   current substantially).

8. **Proto version negotiation / old firmware.** *Recommendation:* app refuses
   `proto < 2` with an "update firmware" message rather than maintaining the
   legacy text-streaming path — simpler and the install base is tiny (beta).

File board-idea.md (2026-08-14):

An ESP32 based "badge" board that can be programmed to be used as a wifi/bluetooth enabled audio recorder
- 55mm x 95mm board, landscape view
- USB C interface for programming and battery charging, centered on the short edge of the board, extends  3-5mm outside the edge of the board to fit the case
- Integrated SDCARD reader, connected to appropriate pins
- Connector for 3.7v 2000mAH battery
- Fuel gauge chip (potentially MAX17048 ) connected to battery and ESP32 for battery monitoring
- 1x populated I2S MEMS microphone (L channel), centered on the 55mm side opposite of the usb c interace, inset 10 mm from the edge of the board
- 1x populated momentary switch, centered between the microphone and the top of the board
- 1x unpopulated area for second momentary switch
- All connectors should be on the front of the board
- 2x holes on top outer edge of board so it can be connected to a lanyard and used as a badge without a case
- 1x hole near the battery connector to allow battery to be mounted on the front or back of the board
- Silkcreen board name somewhere it will fit nicely "Prawnd - Private AI Recording"

CRITICAL: Use only parts with a part number. I must be able to order a fully assembled board when this is complete.

See github.com/hashtagcyber/prawnd for prototype information

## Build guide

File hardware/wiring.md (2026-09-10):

# Prawnd — Wiring

## Bill of materials
- 1× Seeed Studio XIAO ESP32C6
- 2× INMP441 I²S MEMS microphone breakout
- 1× 6-pin micro-SD SPI card adapter — mini 3.3 V variant, pin order
  `GND MISO CLK MOSI CS 3V3`, **no onboard regulator/level shifter** (the
  5 V "HW-125"/Catalex modules with an AMS1117 + 74LVC125 will NOT run from
  3.3 V — the card browns out and never answers)
- 1× momentary push-button (any small tactile switch)
- 1× LED (recording indicator) + 1× 330 Ω–1 kΩ series resistor
- 2× 100 nF ceramic capacitors (decoupling, one per mic)
- A short jumper wire from `3V3` to one mic's `L/R` and from `GND` to the other's `L/R`
- *(optional)* 1× MAX17048 LiPo fuel-gauge breakout + a single-cell LiPo — only for the battery-monitoring addon (see [Battery fuel gauge](#battery-fuel-gauge--max17048-optional-addon))

## Pin map

| XIAO pin | GPIO | Direction | Connects to | Notes |
|---|---|---|---|---|
| `3V3` | — | PWR out | both mics' VDD, SD VCC, Mic-R L/R | 100 nF cap close to each mic's VDD. SD adapter must be 3.3 V. |
| `GND` | — | GND | every peripheral GND, button's other leg, LED cathode, Mic-L L/R | Star ground at the XIAO if layout allows. |
| `D2` | 2 | OUT | I²S BCLK → both mics' SCK | Shared. |
| `D1` | 1 | OUT | I²S WS / LRCLK → both mics' WS | Shared. |
| `D0` | 0 | IN  | I²S DIN ← both mics' SD (tied together) | Shared data line; the L/R pins tri-state each mic on the opposite slot. |
| `D8` | 19 | IN  | SD MISO (a.k.a. DO) | Swapped from the C6 default via GPIO matrix — gives carrier rev 2 crossing-free routing. |
| `D9` | 20 | OUT | SD CLK (a.k.a. SCK) | Swapped from the C6 default (see above). |
| `D10` | 18 | OUT | SD MOSI (a.k.a. DI) | Default SPI MOSI. |
| `D3` | 21 | OUT | SD CS | Software-controlled. |
| `D7` | 17 | IN  | Button (other leg → GND) | Firmware sets `INPUT_PULLUP`, active-low. |
| `D6` | 16 | OUT | Recording LED (via series resistor → LED anode; cathode → GND) | Driven HIGH only while recording. |
| `D4` | 22 | I/O | Fuel-gauge SDA *(optional)* | I²C data — **only** for the battery-monitoring addon. Unused by the base firmware. |
| `D5` | 23 | I/O | Fuel-gauge SCL *(optional)* | I²C clock — **only** for the battery-monitoring addon. Unused by the base firmware. |

### Mic L/R strapping (this picks left vs right)
- **Mic-L**: `L/R → GND` → drives the **left** (WS-low) I²S slot
- **Mic-R**: `L/R → 3V3` → drives the **right** (WS-high) I²S slot
- Never leave `L/R` floating — the INMP441 needs it tied to a rail to select its slot.

## Diagrams (per device)

Wire one device at a time, verify with the bring-up sketches in the plan, then move to the next.

### INMP441 — Left mic

```mermaid
flowchart LR
    subgraph XIAO[XIAO ESP32C6]
        X3V3[3V3]
        XGND[GND]
        XD2[D2 / GPIO2]
        XD1[D1 / GPIO1]
        XD0[D0 / GPIO0]
    end
    subgraph ML[INMP441 Left]
        LV[VDD]
        LG[GND]
        LB[SCK]
        LW[WS]
        LO[SD]
        LS[L/R]
    end
    X3V3 --- LV
    XGND --- LG
    XGND --- LS
    XD2 --- LB
    XD1 --- LW
    XD0 --- LO
```

```
INMP441 (L)  VDD  --- 3V3      (XIAO 3V3 rail)
             GND  --- GND      (XIAO GND rail)
             SCK  --- D2       (GPIO2,  I2S BCLK)
             WS   --- D1       (GPIO1,  I2S WS)
             SD   --- D0       (GPIO0,  I2S DIN, shared with Mic-R)
             L/R  --- GND      (selects the LEFT slot)
```

### INMP441 — Right mic

```mermaid
flowchart LR
    subgraph XIAO[XIAO ESP32C6]
        X3V3[3V3]
        XGND[GND]
        XD2[D2 / GPIO2]
        XD1[D1 / GPIO1]
        XD0[D0 / GPIO0]
    end
    subgraph MR[INMP441 Right]
        RV[VDD]
        RG[GND]
        RB[SCK]
        RW[WS]
        RO[SD]
        RS[L/R]
    end
    X3V3 --- RV
    X3V3 --- RS
    XGND --- RG
    XD2 --- RB
    XD1 --- RW
    XD0 --- RO
```

```
INMP441 (R)  VDD  --- 3V3      (XIAO 3V3 rail)
             GND  --- GND      (XIAO GND rail)
             SCK  --- D2       (GPIO2,  I2S BCLK, shared with Mic-L)
             WS   --- D1       (GPIO1,  I2S WS,   shared with Mic-L)
             SD   --- D0       (GPIO0,  I2S DIN,  shared with Mic-L)
             L/R  --- 3V3      (selects the RIGHT slot)
```

### microSD adapter

```mermaid
flowchart LR
    subgraph XIAO[XIAO ESP32C6]
        X3V3[3V3]
        XGND[GND]
        XD8[D8 / GPIO19]
        XD9[D9 / GPIO20]
        XD10[D10 / GPIO18]
        XD3[D3 / GPIO21]
    end
    subgraph SD[microSD adapter]
        SV[VCC]
        SG[GND]
        SK[CLK / SCK]
        SMI[MISO / DO]
        SMO[MOSI / DI]
        SC[CS]
    end
    X3V3 --- SV
    XGND --- SG
    XD9 --- SK
    XD8 --- SMI
    XD10 --- SMO
    XD3 --- SC
```

```
microSD      VCC      --- 3V3      (3.3V variant adapter — confirm silkscreen)
             GND      --- GND
             CLK/SCK  --- D9       (GPIO20, SPI SCK)
             MISO/DO  --- D8       (GPIO19, SPI MISO)
             MOSI/DI  --- D10      (GPIO18, SPI MOSI)
             CS       --- D3       (GPIO21)
```

Carrier-board note: the J7 header on carrier **rev 2** is ordered
`GND MISO CLK MOSI CS 3V3` (pin 1 → 6) so the mini 3.3 V module drops
straight in, and SCK/MISO are swapped onto GPIO20/GPIO19 (the C6's GPIO
matrix doesn't care) so all three SPI data lines route as parallel traces
with no crossing. Rev 1 boards (first OSH Park run) used the HW-125-style
order `GND VCC MISO MOSI SCK CS` with SCK=GPIO19/MISO=GPIO20 — current
firmware does NOT run rev 1's SD without swapping those two wires or
reverting the two pins in `firmware/include/pins.h`.

### Button

```mermaid
flowchart LR
    subgraph XIAO[XIAO ESP32C6]
        XGND[GND]
        XD7[D7 / GPIO17]
    end
    BTN((Push button))
    XD7 --- BTN
    BTN --- XGND
```

```
Push button  leg A    --- D7       (GPIO17, INPUT_PULLUP in firmware)
             leg B    --- GND
```

### Recording LED

Lit while the device is recording (`State::Recording`), off otherwise. Any
plain LED works; pick the resistor for the brightness you want (330 Ω ≈ 5 mA
at 3.3 V for a red LED, 1 kΩ ≈ 1.5 mA — a fine "is it running" glow and
gentler on the battery).

```mermaid
flowchart LR
    subgraph XIAO[XIAO ESP32C6]
        XGND[GND]
        XD6[D6 / GPIO16]
    end
    R[330 Ω – 1 kΩ]
    LED>LED]
    XD6 --- R
    R --- LED
    LED --- XGND
```

```
LED   anode (+)  --- resistor --- D6   (GPIO16, HIGH while recording)
      cathode (-) --- GND
```

### Battery fuel gauge — MAX17048 (optional addon)

Only needed if you flash the `xiao_esp32c6_batt` firmware. Skip this entire
section for the standard USB-powered build — `D4`/`D5` stay unused.

The gauge sits **inline between the LiPo and the XIAO's BAT pads** (on the
underside of the board) and reports state-of-charge over I²C. It needs no
sense resistor — it's a voltage-based ModelGauge part.

```mermaid
flowchart LR
    BATT[(LiPo cell)]
    subgraph FG[MAX17048 gauge]
        FV[VDD]
        FG2[GND]
        FSDA[SDA]
        FSCL[SCL]
        FBIN[BAT in]
        FBOUT[BAT out]
    end
    subgraph XIAO[XIAO ESP32C6]
        X3V3[3V3]
        XGND[GND]
        XD4[D4 / GPIO22]
        XD5[D5 / GPIO23]
        XBAT[BAT pads -]
    end
    BATT --- FBIN
    FBOUT --- XBAT
    X3V3 --- FV
    XGND --- FG2
    XD4 --- FSDA
    XD5 --- FSCL
```

```
MAX17048   VDD      --- 3V3      (XIAO 3V3 rail)
           GND      --- GND      (XIAO GND rail)
           SDA      --- D4       (GPIO22, I2C SDA)   [optional]
           SCL      --- D5       (GPIO23, I2C SCL)   [optional]
           BAT in   --- LiPo +   (cell connects to the gauge)
           BAT out  --- XIAO BAT+ pad (underside)
LiPo -     --------------- XIAO BAT- pad (underside)
```

Notes:
- `D4`/`D5` are the XIAO's default I²C pins and are free in the base wiring.
- The MAX17048 I²C address is `0x36`; the firmware reads the `VCELL` (voltage)
  and `SOC` (percent) registers directly — no extra library.
- If no gauge is fitted (or you flash the base firmware), the device behaves
  exactly as before and simply reports `battery: n/a` on the config page.

## XIAO ESP32C6 pinout reference

```
                    XIAO ESP32C6 (top-down)
                    +-----------------------+
              3V3 --|                       |-- GND
   I2S DIN    D0 --|  (USB-C at this edge) |-- D10  SD MOSI/DI
   I2S WS     D1 --|                       |-- D9   SD CLK/SCK
   I2S BCLK   D2 --|                       |-- D8   SD MISO/DO
   SD CS      D3 --|                       |-- D7   BUTTON
  SDA (opt)   D4 --|                       |-- D6   REC LED
  SCL (opt)   D5 --|                       |
                    +-----------------------+
```

## Caveats

1. The INMP441's SD output ramps/settles for a few ms after BCLK starts. The firmware (`audio.cpp::audioDropSettle`) drops the first ~1600 samples so this doesn't end up in the WAV.
2. Both mics drive the **same** SD wire. This works because each mic tri-states its SD during the opposite slot, gated by the L/R pin. Do not substitute a non-tri-stating mic without revisiting the bus.
3. The INMP441 has a small DC offset; tolerable for voice. Add a software high-pass at ~20 Hz later if you start visualising the waveform.
4. ESP32-C6 boot-strap pins are `GPIO8` and `GPIO9` — neither is used here.
5. The micro-SD card must be formatted **FAT32**. The Arduino `SD` library does not handle exFAT or large-block FAT16.
6. Empirical gain in `audio.cpp` is `4×` after the shift. Tune up or down at bring-up so normal speech peaks around −6 dBFS.

## Optional follow-up
A polished schematic (KiCad) or breadboard render (Fritzing) is nice-to-have but not required to build v1 — every connection is on this page.

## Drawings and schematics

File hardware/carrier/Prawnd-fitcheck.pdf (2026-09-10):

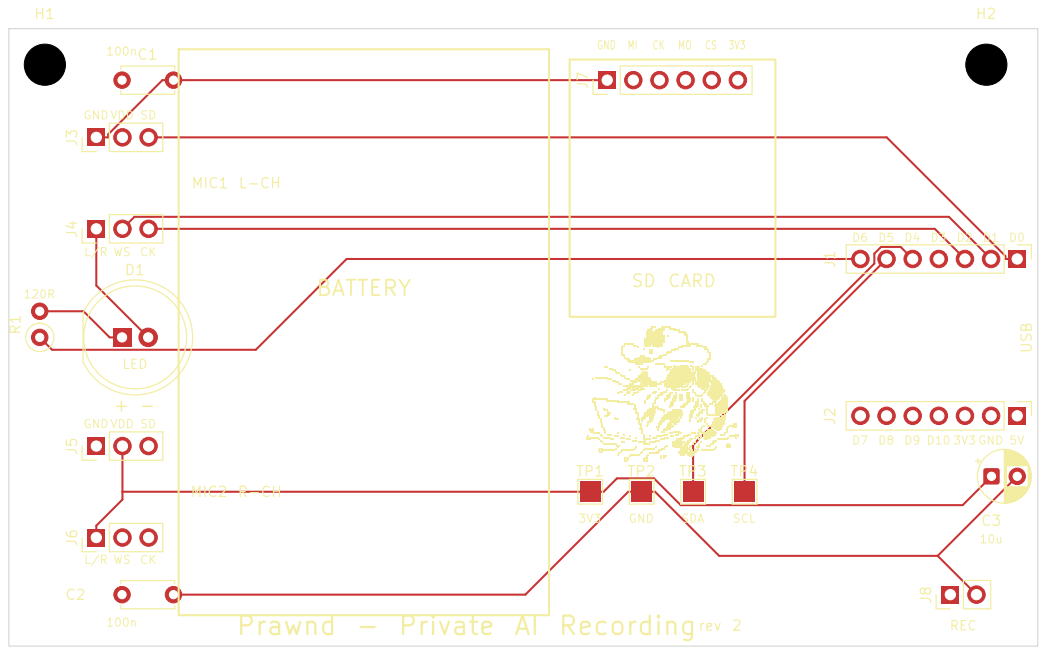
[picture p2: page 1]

GND MI CK MO CS 3V3

Prawnd - Private AI Recording

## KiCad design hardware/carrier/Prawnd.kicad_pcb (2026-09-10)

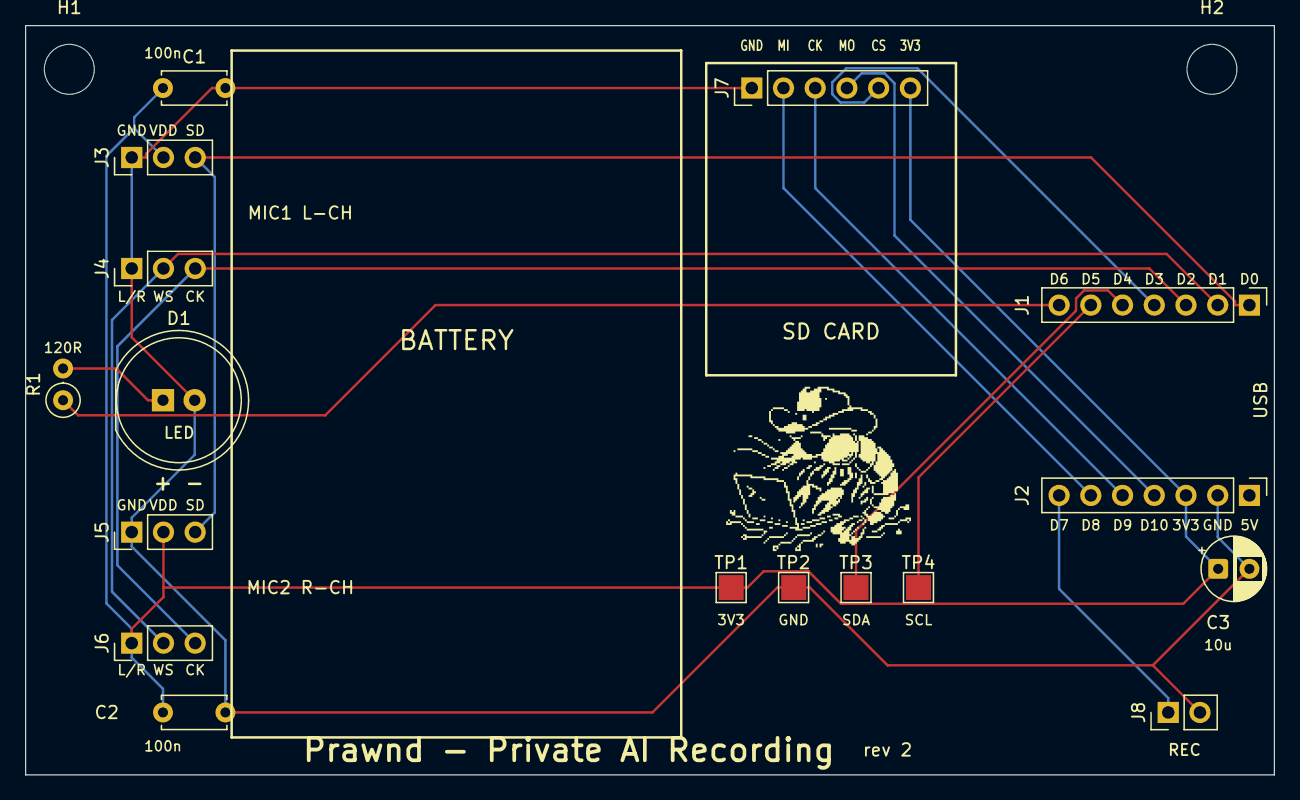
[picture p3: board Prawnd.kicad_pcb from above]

Board: 2 copper layers, 100.0 x 60.0 mm, 19 parts (0 on the bottom side), 14 nets.

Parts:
C1, C2: 100n; C_Disc_D5.0mm_W2.5mm_P5.00mm
C3: 10u; CP_Radial_D5.0mm_P2.50mm
D1: LED_D10.0mm
H1, H2: Lanyard; MountingHole_4mm
J1: ESP32 L; PinHeader_1x07_P2.54mm_Vertical
J2: ESP32 R; PinHeader_1x07_P2.54mm_Vertical
J3: Mic1 R; PinHeader_1x03_P2.54mm_Vertical
J4: Mic1 L; PinHeader_1x03_P2.54mm_Vertical
J5: Mic2 R; PinHeader_1x03_P2.54mm_Vertical
J6: Mic2 L; PinHeader_1x03_P2.54mm_Vertical
J7: SD Card; PinHeader_1x06_P2.54mm_Vertical
J8: BTN; PinHeader_1x02_P2.54mm_Vertical
R1: 120R; R_Axial_DIN0207_L6.3mm_D2.5mm_P2.54mm_Vertical
TP1: +3V3; TestPoint_Pad_2.0x2.0mm
TP2: GND; TestPoint_Pad_2.0x2.0mm
TP3: SDA; TestPoint_Pad_2.0x2.0mm
TP4: SCL; TestPoint_Pad_2.0x2.0mm

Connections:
+3V3: C1.1, C2.1, C3.1, J2.3, J3.2, J5.2, J6.1, J7.6, TP1.1
BTN_D7: J2.7, J8.1
GND: C1.2, C2.2, C3.2, D1.LED-GND, J2.2, J3.1, J4.1, J5.1, J7.1, J8.2, TP2.1
I2C_SCL: J1.6, TP4.1
I2C_SDA: J1.5, TP3.1
I2S_BCLK: J1.3, J4.3, J6.3
I2S_SD: J1.1, J3.3, J5.3
I2S_WS: J1.2, J4.2, J6.2
LED_A: D1.LED-D6, R1.2
LED_D6: J1.7, R1.1
SD_CS: J1.4, J7.5
SD_MISO: J2.6, J7.2
SD_MOSI: J2.4, J7.4
SD_SCK: J2.5, J7.3

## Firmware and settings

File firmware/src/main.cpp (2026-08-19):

#include <Arduino.h>
#include <SD.h>
#include <SPI.h>
#include <NimBLEDevice.h>
#include <freertos/FreeRTOS.h>
#include <freertos/stream_buffer.h>
#include <esp_pm.h>
#include "pins.h"
#include "config.h"
#include "sd_mount.h"
#include "button.h"
#include "audio.h"
#include "wav.h"
#include "battery.h"
#include "ble_sync.h"

// Post-WiFi-removal state machine: the phone (over BLE) is the sole uplink.
//   Boot      transient pre-init state
//   Idle      advertising + serving BLE sync; short press -> record
//   Recording capturing audio to SD via two FreeRTOS tasks; BLE not serviced
enum class State { Boot, Idle, Recording };

static State    state = State::Boot;
static Config   cfg;
static File     recFile;
static String   recPath;
static volatile uint32_t recordedBytes = 0;

// --- Recording pipeline (FreeRTOS) ----------------------------------------
// audioReaderTask: blocks on I2S, applies filters, pushes int16 frames into a
// 64 KB stream buffer. sdWriterTask: drains the buffer in 4 KB chunks and
// writes to the open WAV file. Decouples the audio sampling cadence from SD
// write bursts — eliminates the 62.5 Hz envelope modulation the old single-
// threaded loop produced.
static StreamBufferHandle_t recStream  = nullptr;
static volatile bool        recStop    = false;
static volatile bool        readerDone = false;
static volatile bool        writerDone = false;

static void audioReaderTask(void *) {
  static int16_t out[256];
  while (!recStop) {
    size_t n = audioReadFrames(out, 256);
    if (n) {
      xStreamBufferSend(recStream, out, n * sizeof(int16_t), portMAX_DELAY);
    }
  }
  readerDone = true;
  vTaskDelete(NULL);
}

static void sdWriterTask(void *) {
  static uint8_t buf[4096];
  while (true) {
    size_t got = xStreamBufferReceive(recStream, buf, sizeof(buf), pdMS_TO_TICKS(100));
    if (got > 0) {
      recordedBytes += recFile.write(buf, got);
    } else if (readerDone && xStreamBufferIsEmpty(recStream)) {
      break;
    }
  }
  writerDone = true;
  vTaskDelete(NULL);
}

static const String PENDING_DIR  = "/pending";
static const String UPLOADED_DIR = "/uploaded";

static void ensureDirs() {
  if (!SD.exists(PENDING_DIR))  SD.mkdir(PENDING_DIR);
  if (!SD.exists(UPLOADED_DIR)) SD.mkdir(UPLOADED_DIR);
}

static bool isRecordingName(const String &base) {
  return base.length() && !base.startsWith(".") && base.endsWith(".wav");
}

// Count valid pending WAVs for the advertised PENDING bit/count.
static uint32_t countPending() {
  if (SD.cardType() == CARD_NONE) return 0;
  File dir = SD.open(PENDING_DIR);
  uint32_t count = 0;
  if (dir) {
    while (true) {
      File entry = dir.openNextFile();
      if (!entry) break;
      String n = String(entry.name());
      entry.close();
      int slash = n.lastIndexOf('/');
      String base = slash >= 0 ? n.substring(slash + 1) : n;
      if (isRecordingName(base)) count++;
    }
    dir.close();
  }
  return count;
}

static uint8_t batteryPct() {
#ifdef ENABLE_BATTERY
  BatteryReading b;
  if (batteryRead(b) && b.percent >= 0 && b.percent <= 100) return (uint8_t)b.percent;
#endif
  return 0xFF;  // unknown
}

// Recompute the advertised pending count + battery and re-advertise (sets the
// PENDING flag bit and the fast/slow interval). Main-loop only.
static void updatePendingAdvertising() {
  bleSyncUpdatePending(countPending(), batteryPct());
}

// --- Power management (esp_pm automatic light sleep) -----------------------
// Light sleep between BLE advertising events is the ~20 mA -> ~2 mA idle win.
// It kills the native USB-Serial/JTAG link, so it's enabled only when no USB
// host is attached: bench (USB) keeps the console, battery sleeps. While a
// phone is connected we hold a NO_LIGHT_SLEEP lock so transfer throughput
// stays up; the I2S driver holds its own PM lock during recording. Caveat:
// a light-sleeping device can't enumerate USB — to get the console back,
// plug in and reset (boot re-checks during the serial wait).
static bool pmConfigured = false;
static bool pmLightSleep = false;
static esp_pm_lock_handle_t pmBleLock = nullptr;
static bool pmBleLockHeld = false;

static void pmApply(bool sleepWanted) {
  // Always configure once at boot (enables DFS to min 40 MHz even on USB);
  // afterwards only on USB attach/detach transitions.
  if (pmConfigured && sleepWanted == pmLightSleep) return;
  esp_pm_config_t pm = {};
  pm.max_freq_mhz = 80;
  pm.min_freq_mhz = 40;
  pm.light_sleep_enable = sleepWanted;
  esp_err_t err = esp_pm_configure(&pm);
  if (err == ESP_OK) {
    pmConfigured = true;
    pmLightSleep = sleepWanted;
    Serial.printf("[pm] light sleep %s\n",
                  sleepWanted ? "ENABLED (no USB host)" : "disabled (USB attached)");
  } else {
    // ESP_ERR_NOT_SUPPORTED here means the libs were built without
    // CONFIG_PM_ENABLE — the custom_sdkconfig rebuild didn't take.
    Serial.printf("[pm] esp_pm_configure failed: %d\n", (int)err);
  }
}

static void pmService() {
  if (pmBleLock) {
    bool link = bleSyncLinkActive();
    if (link != pmBleLockHeld) {
      if (link) esp_pm_lock_acquire(pmBleLock);
      else      esp_pm_lock_release(pmBleLock);
      pmBleLockHeld = link;
    }
  }
  static uint32_t lastCheck = 0;
  if (millis() - lastCheck < 1000) return;
  lastCheck = millis();
  // Gate on CABLE presence (HWCDC tracks USB frames), NOT on whether a
  // terminal has the port open — usb_serial_jtag_is_connected() flips false
  // when the port is merely closed, which put a bench-powered device to
  // sleep with the cable in and bricked USB until replug.
  pmApply(!Serial.isPlugged());
}

static void startRecording() {
  if (!sdEnsureMounted()) {
    Serial.println("No SD card; cannot record");
    return;
  }
  recPath = String("/rec_") + String(millis()) + ".wav";
  recFile = SD.open(recPath, FILE_WRITE);
  if (!recFile) {
    Serial.printf("Failed to open %s\n", recPath.c_str());
    return;
  }
  wavWritePlaceholderHeader(recFile, 16000, 2, 16);
  recordedBytes = 44;
  if (!audioBegin()) {
    Serial.println("audioBegin failed");
    recFile.close();
    SD.remove(recPath);
    return;
  }
  audioDropSettle();

  // Spin up the two-task recording pipeline.
  recStream  = xStreamBufferCreate(64 * 1024, 1024);
  recStop    = false;
  readerDone = false;
  writerDone = false;
  xTaskCreate(audioReaderTask, "audio_rdr", 4096, NULL, 10, NULL);
  xTaskCreate(sdWriterTask,    "sd_wr",     4096, NULL, 5,  NULL);

  state = State::Recording;
  digitalWrite(PIN_REC_LED, HIGH);
  Serial.printf("Recording -> %s\n", recPath.c_str());
}

static void stopRecording() {
  // Signal reader → it exits the next loop iteration. Writer drains then
  // exits. Wait for both with generous timeouts.
  recStop = true;
  uint32_t t0 = millis();
  while (!readerDone && millis() - t0 < 5000) delay(10);
  while (!writerDone && millis() - t0 < 10000) delay(10);
  audioEnd();
  if (recStream) { vStreamBufferDelete(recStream); recStream = nullptr; }

  uint32_t total = recordedBytes;
  recFile.close();
  if (!wavPatchSizes(recPath.c_str(), total)) {
    Serial.printf("WAV header patch failed for %s\n", recPath.c_str());
  }
  String target = PENDING_DIR + "/" + String(millis()) + ".wav";
  SD.rename(recPath, target);
  state = State::Idle;
  digitalWrite(PIN_REC_LED, LOW);
  Serial.printf("Stopped, queued %s (%u bytes)\n", target.c_str(), (unsigned)total);

  // New pending file: set the PENDING adv bit + fast interval so the phone
  // wakes and drains. Increment the advertised count rather than re-walking
  // /pending (which would need the SD card for a number we already know).
  bleSyncUpdatePending(bleSyncPendingCount() + 1, batteryPct());
}

void setup() {
  // 80 MHz is ample (audio filtering is a few hundred kcycles/s, SD SPI is
  // 1 MHz, I2S is DMA) and cuts ~10 mA off the always-active baseline.
  setCpuFrequencyMhz(80);
  Serial.begin(115200);
  // Native USB-CDC re-enumerates after reset, so the host needs a moment to
  // reopen the port. Wait (bounded) so boot logs aren't lost; the timeout
  // keeps battery-powered boots from stalling when no host is attached.
  uint32_t serialWaitStart = millis();
  while (!Serial && millis() - serialWaitStart < 3000) delay(10);
  delay(200);
  Serial.println("\nPrawnd boot");

  buttonBegin();
  pinMode(PIN_REC_LED, OUTPUT);
  digitalWrite(PIN_REC_LED, LOW);  // recording indicator off until startRecording()
  audioParkPins();  // defined levels for the mic clock/data lines until recording

  // 16 kHz × 2ch × 2B = 64 KB/s of audio data — at 400 kHz SPI the card
  // tops out around 50 KB/s and DMA overruns produce robotic-sounding
  // recordings. 1 MHz gives ~125 KB/s, comfortable headroom. (Bus speed is
  // set in sd_mount.cpp; the card is lazily mounted and idles unmounted.)
  if (!sdEnsureMounted()) {
    Serial.println("SD init failed");
  } else {
    Serial.printf("SD ok: %u MB total, %u MB free\n",
                  (uint32_t)(SD.totalBytes() / 1024 / 1024),
                  (uint32_t)((SD.totalBytes() - SD.usedBytes()) / 1024 / 1024));
    ensureDirs();
  }

#ifdef ENABLE_BATTERY
  if (batteryBegin()) {
    BatteryReading b;
    if (batteryRead(b)) Serial.printf("Battery gauge: %d%% (%d mV)\n", b.percent, b.millivolts);
    else                Serial.println("Battery gauge present but read failed");
  } else {
    Serial.println("Battery gauge not detected on I2C (addon build)");
  }
#endif

  loadConfig(cfg);  // device_id only
  Serial.printf("Config: dev=%s\n", cfg.device_id.c_str());

  // BLE is the sole uplink. Sets up the GATT service (CTRL/STAT/DATA/CFG),
  // security (Just-Works bonding), the resolving list, and starts advertising.
  bleSyncBegin(cfg.device_id);
  // Reflect the pending queue in the advertisement at boot.
  updatePendingAdvertising();

  esp_pm_lock_create(ESP_PM_NO_LIGHT_SLEEP, 0, "ble_link", &pmBleLock);
  pmApply(!Serial.isPlugged());

  state = State::Idle;
}

void loop() {
  // Serial console. The board's physical RST drops native USB hard enough that
  // the host may not re-enumerate without a replug; ESP.restart() keeps the
  // USB-Serial/JTAG peripheral alive, so 'r' is the way to reboot at the bench.
  while (Serial.available()) {
    char c = Serial.read();
    if (c == 'r') {
      Serial.println("[cmd] rebooting (software reset, USB stays up)");
      delay(100);
      ESP.restart();
    } else if (c == '?') {
      Serial.println("[cmd] r=reboot  ?=help");
    }
  }

  // Unmount the SD card after idle (power); never while recording or while a
  // phone is connected (an in-flight GET holds an open file handle).
  sdIdleMaintain(state == State::Recording || bleSyncLinkActive());
  pmService();

  if (buttonLongPressed()) {
    Serial.println("Long press: factory reset");
    clearConfig();
    NimBLEDevice::deleteAllBonds();  // bonds live in a separate NVS namespace
    delay(200);
    ESP.restart();
  }

  if (buttonTriplePressed() && state != State::Recording) {
    Serial.println("Triple press: opening BLE pairing window");
    bleSyncEnterPairing();
  }

  switch (state) {
    case State::Boot:
      delay(20);
      break;
    case State::Idle:
      bleSyncService();  // advances LIST/GET window/ACK/CFG + pairing timer
      if (buttonShortPressed()) {
        startRecording();
      } else {
        delay(5);  // tight loop so the streaming window stays fed
      }
      break;
    case State::Recording:
      // Audio + SD writes happen in background tasks; BLE is intentionally NOT
      // serviced here (no SD contention). A connected phone's in-flight GET
      // times out and resumes after recording stops.
      if (buttonShortPressed()) {
        stopRecording();
      } else {
        delay(20);
      }
      break;
  }
}

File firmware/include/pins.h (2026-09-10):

#pragma once
#include <Arduino.h>

// I2S (shared bus for both INMP441 mics)
constexpr int PIN_I2S_BCLK = 2;   // D2
constexpr int PIN_I2S_WS   = 1;   // D1
constexpr int PIN_I2S_DIN  = 0;   // D0

// SD card (SPI). SCK/MISO are swapped from the C6 defaults via the GPIO
// matrix: carrier rev 2 routes J7 crossing-free this way. (Rev 1 boards and
// the original point-to-point wiring used SCK=19/MISO=20.)
constexpr int PIN_SD_SCK   = 20;  // D9
constexpr int PIN_SD_MISO  = 19;  // D8
constexpr int PIN_SD_MOSI  = 18;  // D10
constexpr int PIN_SD_CS    = 21;  // D3

// Button (active-low with internal pull-up)
constexpr int PIN_BUTTON   = 17;  // D7

// Recording indicator LED (external, D6 -> series resistor -> LED -> GND).
// Driven HIGH while recording, LOW otherwise.
constexpr int PIN_REC_LED  = 16;  // D6

// Battery fuel gauge (optional addon — MAX17048 over I2C).
// Only used when the firmware is built with -DENABLE_BATTERY
// (the `xiao_esp32c6_batt` PlatformIO env). These are the XIAO's default
// I2C pins and are otherwise unused by the base firmware.
constexpr int PIN_BATT_SDA = 22;  // D4
constexpr int PIN_BATT_SCL = 23;  // D5

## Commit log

2026-06-11 hardware: swap mic to INMP441 in wiring docs
    Replace SPH0645 with INMP441 across the wiring diagram, BOM, and
    firmware pin comment. Pin names map SCK->BCLK, WS->WS, SD->DIN, and
    L/R->slot strap (GND=left, 3V3=right); the shared tri-stated data bus
    and GPIO assignments are unchanged.
    [pins.h]
2026-06-14 fix(firmware): use WiFiClientSecure for https uploads (+ README TLS warning)
    The uploader used a plain WiFiClient for all URLs. Pointed at an https:// URL
    (e.g. the hosted prawnd.dev.cobl.io behind Cloudflare) it opened a raw socket to
    :443 and wrote cleartext, so the TLS edge replied "400 Bad Request - The plain
    HTTP request was sent to HTTPS port" and uploads never authenticated.
    Pick the transport by URL scheme: WiFiClientSecure (with setInsecure()) for
    https://, plain WiFiClient for http://. Uploads to the hosted service now
    complete.
    setInsecure() disables certificate validation (encrypted but MITM-able — the API
    key rides the link). Documented with a prominent CAUTION block in READ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
2026-06-14 add battery support and idea file
2026-06-15 firmware: BLE sync transport with button-gated pairing mode
    NimBLE GATT service so a companion app can pull queued recordings off the SD
    card over Bluetooth LE — an alternate uplink to the WiFi uploader, draining the
    same on-SD /pending -> /uploaded queue.
    - ble_sync.{h,cpp}: GATT service (Control/Status/Data chars), tab-delimited
    LIST/GET/ACK protocol. BLE callbacks only enqueue commands; SD I/O happens in
    the main loop so SD access stays single-threaded.
    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
2026-06-15 docs: correct mic part to INMP441 in README
    The hardware blurb still said SPH0645; the wiring docs and firmware use INMP441.
2026-06-15 firmware: remove WiFi, make BLE the sole uplink with reliable auto-sync
    Rearchitecture per docs/ble-autosync-spec.md (Section B = frozen BLE contract
    shared with the iOS app).
    - Delete wifi_mgr/portal/uploader; strip ApPortal/StaIdle/Uploading states.
    The phone-over-BLE path is now the only uplink; firmware no longer holds the
    server URL or API key.
    - device_id is configured over a new BLE CFG characteristic (E2C50004).
    - Advertising v2: SVC UUID in the primary packet + PENDING/PAIRING/BUSY mfg-data
    flags so iOS can discover-and-wake in the background.
    - Fix RPA reconnect (bug #1): drop the onConnect !isBonded() gate; rely on
    WRITE_ENC + pairing-window-gated bond creation.
    - Reliabl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
    [ble_sync.cpp, main.cpp]
2026-08-14 firmware: bench debug tools + battery-life optimizations
    Debug/bench:
    - Boot waits up to 3s for the USB-CDC host so boot logs survive re-enumeration
    - [btn] event logging; [ble<]/[ble>] sync protocol logging + GET progress
    - Serial 'r' command reboots via ESP.restart() (native USB stays up; the
    physical RST drops USB hard enough macOS may not re-enumerate)
    - reset-device.sh: esptool-based USB reset without the physical button
    Power (from ESP32-C6 review; ~2.3 -> ~5-6 days est. on the 2000mAh cell):
    - CPU 160 -> 80 MHz (audio DSP is trivial; SD SPI is 1 MHz; I2S is DMA)
    - BLE TX +9 dBm (C6 default) -> 0 dBm
    - SD card lazily mounted, unmounted after 20s idle (never while recording or
    whil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
    [audio.cpp, ble_sync.cpp, button.cpp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]
2026-08-14 board-idea: landscape layout, mic/button placement, orderable-parts requirement
2026-08-19 firmware: esp_pm auto light sleep + recording LED — week-long battery life
    Rebuild the framework libs with power management via pioarduino's
    custom_sdkconfig (PM_ENABLE, tickless idle, BLE controller sleep, RF
    MAC/baseband power-down); Arduino's bundled cloud components are removed
    (esp_insights' cert-embed step breaks the hybrid compile, and none are
    used). huge_app.csv is vendored because hybrid builds resolve the
    partition table against the project dir. Generated hybrid-build artifacts
    (managed_components/ etc.) are gitignored.
    Light sleep is gated on USB cable presence via Serial.isPlugged() — bench
    keeps the console, battery sleeps between BLE advertisements. Gate on
    cable presence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
    [huge_app.csv]
2026-08-19 hardware: add the carrier board KiCad project
    100x60mm carrier for the XIAO ESP32-C6 prototype: 2x INMP441 (8.89mm row
    pairs), 20x25 SD bay, 36x55 battery bay, record button + LED (D6/GPIO16),
    fuel-gauge solder pads (3V3/GND/SDA/SCL), lanyard holes. Routed
    (Freerouting) with a back GND pour, DRC-clean against OSH Park 2-layer
    rules — the .kicad_pcb uploads to OSH Park directly. PCB-only design: the
    netlist is the schematic (the .kicad_sch is an empty stub); it was
    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
    [Prawnd.kicad_pcb, Prawnd.kicad_sch]
2026-09-10 hardware: carrier rev 2 — J7 reordered for mini 3.3V SD module; bench-test firmware
    Rev 1's J7 used the HW-125-style order (GND VCC MISO MOSI SCK CS), but
    HW-125 modules are 5V boards (AMS1117 + level shifter) and brown out on
    the carrier's 3.3V rail — the card never answers GO_IDLE. Rev 2 targets
    the regulator-less mini 3.3V module instead:
    - J7 reordered to GND MISO CLK MOSI CS 3V3 (pin 1→6), silk updated
    - SD_SCK/SD_MISO swapped onto GPIO20/GPIO19 via the C6 GPIO matrix so
    all three SPI lines route as parallel B.Cu diagonals — no crossings,
    no vias; pins.h updated to match (rev 1 SD wiring no longer matches
    firmware — swap the two wires or revert pins.h to bench SD on rev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
    [Prawnd.kicad_pcb]
2026-09-10 hardware: fix illegible silk labels, stamp rev 2
    Rev 1 fab exposed several silk collisions that printed as mush or not at
    all: C3's refdes sat on J2's 5V/GND pin labels (the mystery unlabeled
    half-shaded circle), the 10u value text crossed C3's own polarity arc and
    GND pad, C2's refdes landed on the mic CK pin label, the LED text printed
    on top of a VDD pin label, and J1/J2's refdes were past the board edge.
    - Relocate C3/C2/J1/J2 refdes and the 10u text to clear ground
    - Move LED inside the D1 circle (visible until the LED is fitted)
    - Bump J7 pin labels 0.7 -> 0.8mm tall (0.6mm wide, still fits the pitch)
    - Add 'rev 2' stamp next to the title text
    - DRC silk warnings 29 -> 7; the rest are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
    [Prawnd.kicad_pcb]
2026-09-27 firmware: recover from stranded GETs (ERR busy), add flash scripts + mictest raw dump
    The phone finishes a GET the moment the last byte lands, usually before its
    final cumulative ACKW goes out, so the device sat in GetState::Draining with
    no timeout and answered every later GET in the session with "ERR busy" until
    the link dropped. Only the first file per connection ever synced.
    - handleGet: a new GET supersedes a transfer that is clearly over (Draining,
    same file re-requested, or no ACKW progress for 10 s) instead of refusing.
    - handleAck: ACK of the in-flight file ends the GET and closes the handle
    (renaming an open FatFs file fails).
    - service loop: 10 s no-progress guard resets a st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
    [ble_sync.cpp, mic_led_test.cpp]
